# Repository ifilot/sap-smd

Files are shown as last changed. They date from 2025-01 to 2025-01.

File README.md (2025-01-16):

# Modular 8-bit "Simple as Possible" TTL-Logics Computer




This project showcases the design and construction of a modular 8-bit computer
built with TTL logic units. The core principle behind the project is to create a
**"Simple as Possible"** system, focusing on simplicity, modularity, and
compactness.

SAP-SMD demo

## Key Features

- **TTL Logic-Based Design**: The computer is built using traditional TTL
  (Transistor-Transistor Logic) components, adhering to a fundamental, hands-on
  approach to computing.
- **Modular Architecture**: Designed for modularity, each functional unit (ALU,
  registers, memory, control logic, etc.) is implemented as a separate module,
  allowing for easy debugging, customization, and scalability.
- **Compact Form Factor**: By predominantly using **SMD (Surface-Mount Device)**
  components, the overall size of the computer is significantly reduced compared
  to traditional through-hole designs, making it more efficient and portable.
- **Educational Value**: Serves as an excellent learning resource for
  understanding the basic principles of digital logic, computer architecture,
  and how these concepts come together to form a functional computing system.
- **Customization Potential**: The modular approach allows users to experiment
  with different configurations and expand the system to suit specific needs or
  projects.

## Technical specifications

- 8 bit program counter
- 256 bytes of RAM and 256 bytes of program ROM
- 256 configurable programs via a dip switch
- Three general-purpose register: A, B and T
- Simple ALU allowing for addition and subtraction
- EEPROM-configurable instruction decoder
- Custom assembly language including Python-based assembler

## Goals of the Project

The project aims to:
1. **Simplify Complexity**: Break down the workings of a computer into
   comprehensible modules without unnecessary abstraction.
2. **Promote Learning**: Provide an accessible platform for enthusiasts,
   educators, and students to explore computer design.
3. **Encourage Miniaturization**: Demonstrate how SMD components can be used
   effectively in hobbyist and educational projects to save space while
   maintaining functionality.

## Why SMD Components?

SMD components offer several advantages:
- **Space Efficiency**: Significantly smaller than through-hole components,
  enabling more compact designs.
- **Modern Availability**: Easier to source and more reflective of contemporary
  electronics practices.
- **Scalability**: Allows for a more complex system without requiring excessive
  physical space.

## Who Is This For?

This project is ideal for:
- **Hobbyists and Makers** interested in retrocomputing and hardware design.
- **Students and Educators** looking for hands-on experience with digital logic
  and computing fundamentals.
- **Researchers and Enthusiasts** exploring minimalist computing and modular
  design approaches.

## Getting Started

1. **Clone the Repository**: Download the files and schematics from this
   repository.
2. **Review the Documentation**: Detailed explanations and schematics for each
   module are available in the `docs` directory.
3. **Assemble and Test**: Follow the provided instructions to assemble and test
   the modules step-by-step.
4. **Customize**: Modify or expand the design to suit your needs or explore
   specific areas of interest.

## Contributing

Contributions to this project are welcome! If you have ideas for improvements,
additional features, or alternative designs, feel free to fork the repository
and submit a pull request.

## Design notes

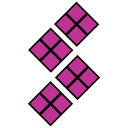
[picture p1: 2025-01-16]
docs/source/_static/img/sap-smd-128px.png

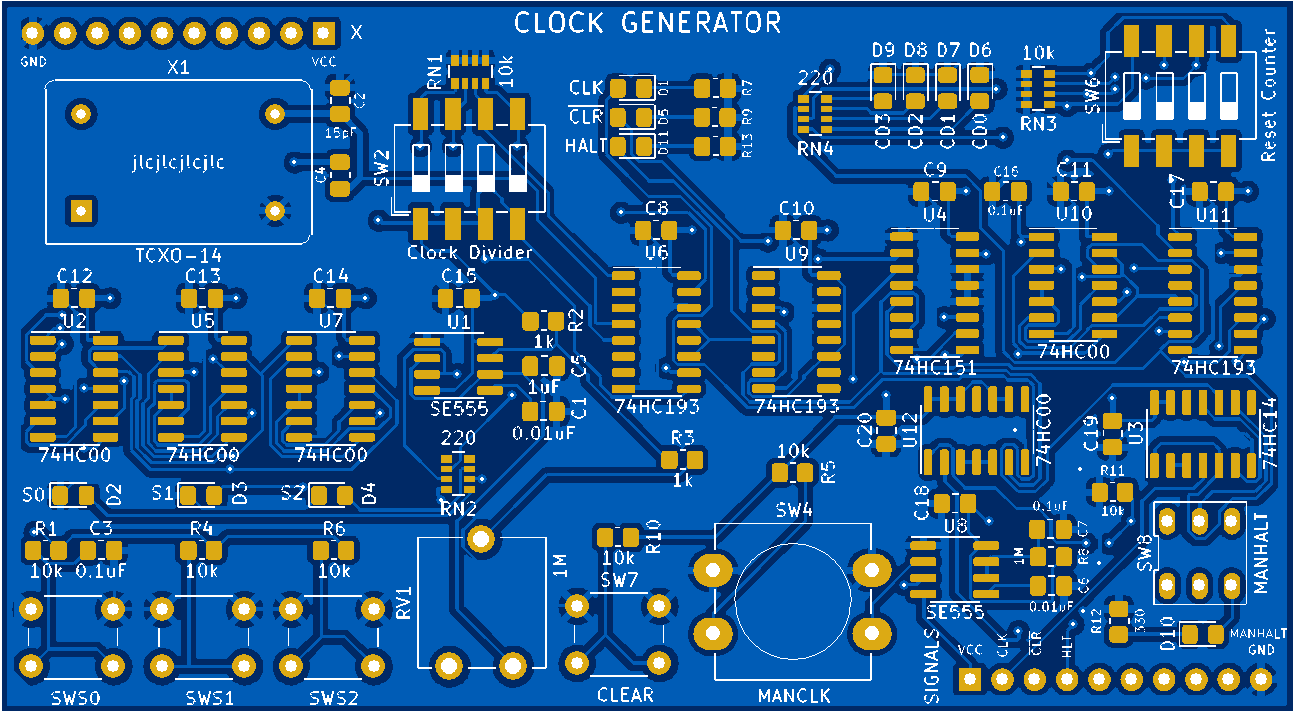
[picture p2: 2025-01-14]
img/clock_generator.png

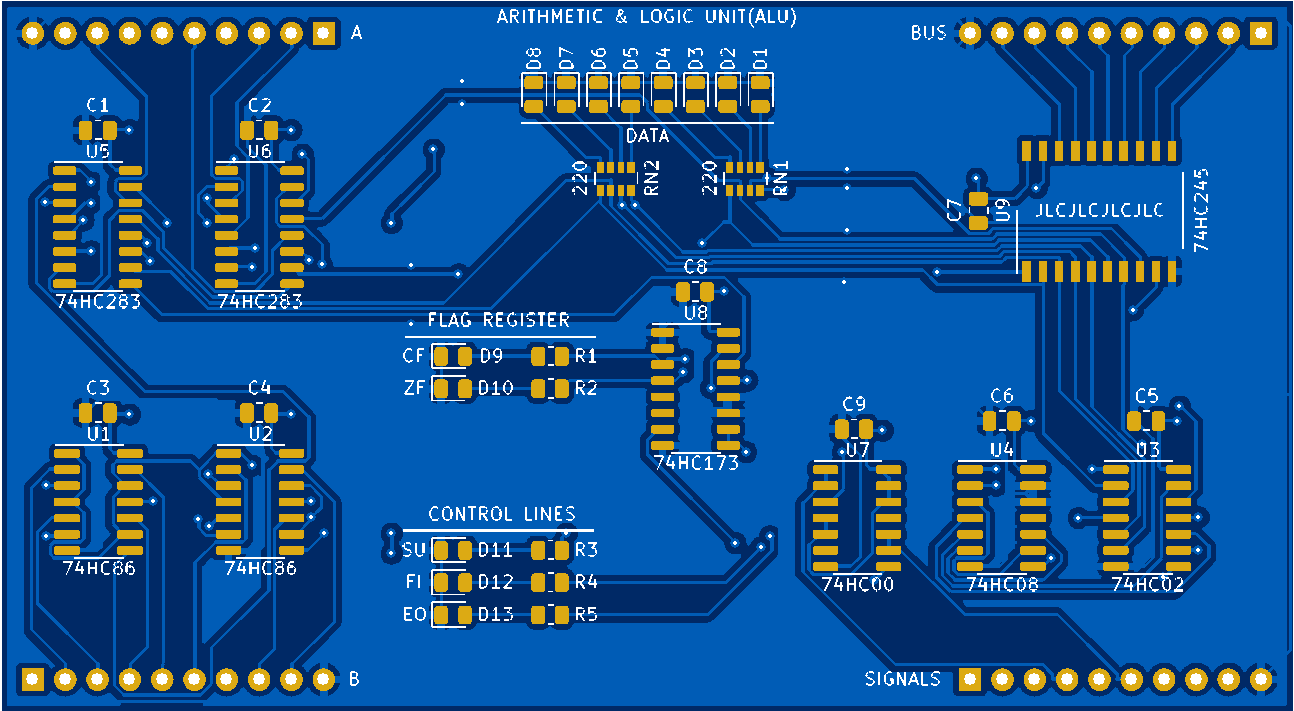
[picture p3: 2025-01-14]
img/arithmetic_and_logic_unit.png

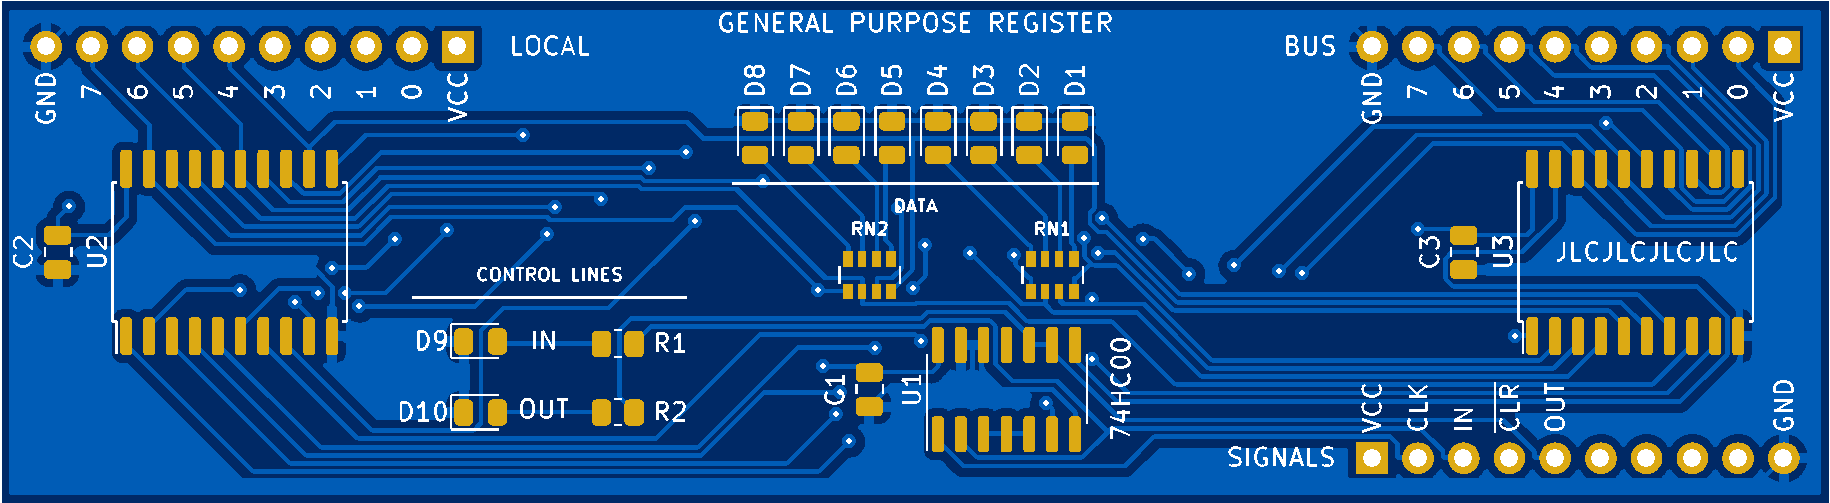
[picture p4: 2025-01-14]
img/general_purpose_register.png

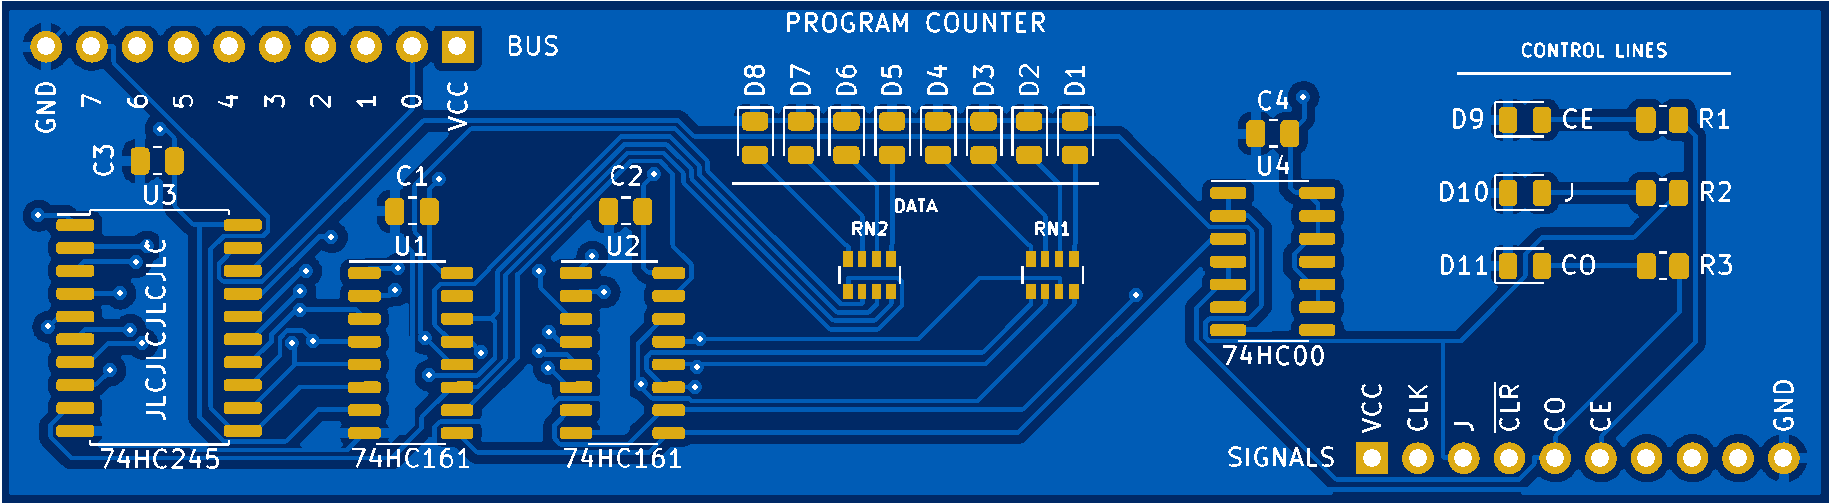
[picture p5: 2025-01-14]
img/program_counter.png

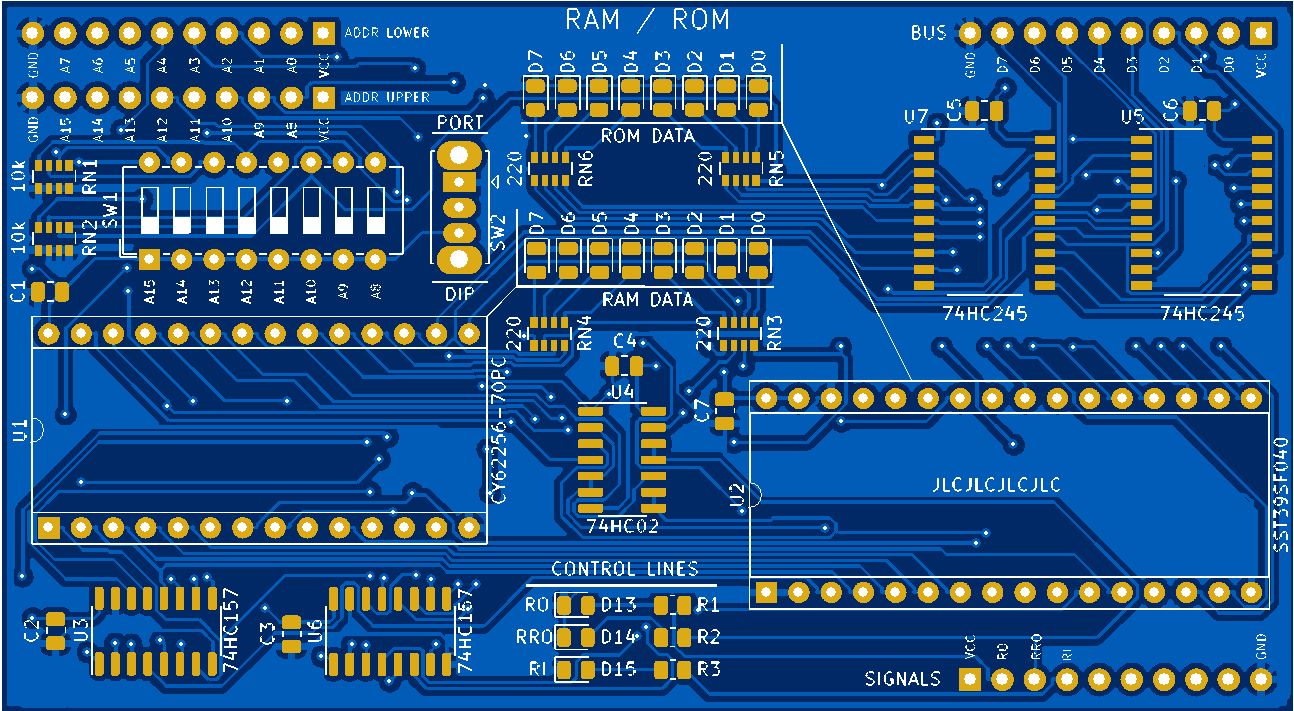
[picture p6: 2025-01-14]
img/ram_rom.png

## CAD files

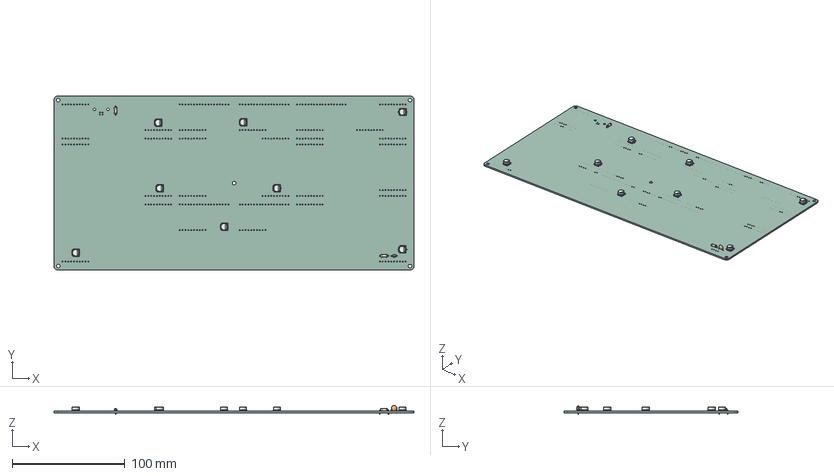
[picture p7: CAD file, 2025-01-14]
pcb/backplates/bp-leanplate/bp-leanplate.step
319.9 x 154.4 x 8.10 mm
CP_Elec_63x39 x 8
R_Axial_DIN0207_L63mm_D25mm_P762mm_Horizontal x 2
C_Disc_D50mm_W25mm_P500mm
bp-leanplate_PCB

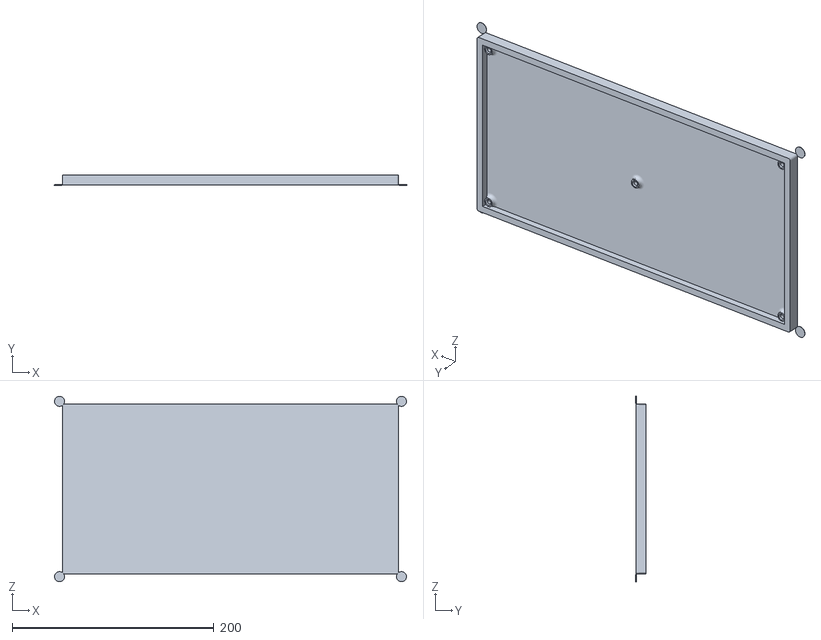
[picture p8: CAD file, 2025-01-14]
pcb/backplates/case/case.stl
349.4 x 10.2 x 184.0

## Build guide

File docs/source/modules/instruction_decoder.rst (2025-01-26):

.. _instruction_decoder:
.. index:: Instruction Decoder

Instruction decoder
===================

The instruction decoder is reponsible for mapping a machine instruction together
with the t-state counter to the control lines, effectively tying a set of
microinstructions to a given machine instruction. The instruction decoder in the
SAM-SMD uses two :code:`SST39SF010` EEPROMS for this mapping. One of the EEPROMS
directs 8 parallel control lines, which are lines that can be pulled high or low
in any particular combination. The second EEPROM is tied to four :code:`74HC238`
which control 2 x 15 orthogonal control lines. Orthogonal control lines are such
that only one of the 15 lines can be activated at one time. This limitation
comes with the benefit that a single chip can control far more control lines,
here 30 instead of 8. Note that the 2 x 15 orthogonal control lines form two
sets, i.e. any control line in one set **can** be activated together with any
other control line in the other set. The only limitation is thus that **within**
a set, no two control lines can be activated simultaneously.

Mapping
-------

.. note::
   In the tables below, we use the following abbreviations:
   * ALU: Arithmetic and Logic Unit
   * IR: Instrucion Register
   * MAR: Memory Address Register
   * PC: Program Counter

.. list-table:: Parallel Control Lines
   :widths: 20, 20, 60
   :header-rows: 1

   * - Control line
     - Micro-instruction
     - Description
   * - :code:`PCL0`
     - :code:`CE`
     - PC count enable
   * - :code:`PCL1`
     - :code:`FI`
     - ALU flag register in
   * - :code:`PCL2`
     - :code:`SU`
     - ALU subtract operation
   * - :code:`PCL3`
     - :code:`X`
     - Unused
   * - :code:`PCL4`
     - :code:`X`
     - Unused
   * - :code:`PCL5`
     - :code:`X`
     - Unused
   * - :code:`PCL6`
     - :code:`HLT`
     - Halts the clock line
   * - :code:`PCL7`
     - :code:`/MR`
     - Used internally to reset T-state counter

.. list-table:: Orthogonal Control Lines A
   :widths: 20, 20, 60
   :header-rows: 1

   * - Control line
     - Micro-instruction
     - Description
   * - :code:`OCA1`
     - :code:`MI`
     - MAR in: Retrieves memory address from data bus
   * - :code:`OCA2`
     - :code:`II`
     - IR in: Retrieves instruction from data bus
   * - :code:`OCA3`
     - :code:`J`
     - PC jump: Retrieves address from data bus
   * - :code:`OCA4`
     - :code:`AI`
     - A-register in: Stores value from data bus
   * - :code:`OCA5`
     - :code:`BI`
     - B-register in: Stores value from data bus
   * - :code:`OCA6`
     - :code:`OI`
     - Output register in: Retrieves value from data bus
   * - :code:`OCA7`
     - :code:`RI`
     - RAM in: Stores value from data bus in memory
   * - :code:`OCA8`
     - :code:`TI`
     - T-register in: Stores value from data bus
   * - :code:`OCA9`
     - :code:`X`
     - Unused
   * - :code:`OCA10`
     - :code:`X`
     - Unused
   * - :code:`OCA11`
     - :code:`X`
     - Unused
   * - :code:`OCA12`
     - :code:`X`
     - Unused
   * - :code:`OCA13`
     - :code:`X`
     - Unused
   * - :code:`OCA14`
     - :code:`X`
     - Unused
   * - :code:`OCA15`
     - :code:`X`
     - Unused

.. list-table:: Orthogonal Control Lines B
   :widths: 20, 20, 60
   :header-rows: 1

   * - Control line
     - Micro-instruction
     - Description
   * - :code:`OCB1`
     - :code:`CO`
     - PC counter out: Asserts current PC value on data bus
   * - :code:`OCB2`
     - :code:`RRO`
     - ROM out: Asserts ROM value onto data bus
   * - :code:`OCB3`
     - :code:`AO`
     - A-register out: Asserts register value onto data bus
   * - :code:`OCB4`
     - :code:`BO`
     - B-register out: Asserts register value onto data bus
   * - :code:`OCB5`
     - :code:`EO`
     - ALU sum out: Asserts result of summation onto data bus
   * - :code:`OCB6`
     - :code:`RO`
     - RAM out: Asserts RAM value onto data bus
   * - :code:`OCB7`
     - :code:`TO`
     - T-register: Asserts register value onto data bus
   * - :code:`OCB8`
     - :code:`X`
     - Unused
   * - :code:`OCB9`
     - :code:`X`
     - Unused
   * - :code:`OCB10`
     - :code:`X`
     - Unused
   * - :code:`OCB11`
     - :code:`X`
     - Unused
   * - :code:`OCB12`
     - :code:`X`
     - Unused
   * - :code:`OCB13`
     - :code:`X`
     - Unused
   * - :code:`OCB14`
     - :code:`X`
     - Unused
   * - :code:`OCB15`
     - :code:`X`
     - Unused

Machine instructions
--------------------

Upon receiving a new machine instruction, a t-state counter is executed that
loops over a number of microinstructions. Below, a table is provided showing
the sequence of microinstructions that are executed per machine instruction
and per t-state. A secondary table provides an explanation what each machine
code instruction (opt code) does.

.. note::
  Despite that the t-state counter allows for up to 20 microinstructions, 
  typically far fewer such microinstructions are needed.

.. list-table:: Microinstructions per t-state and per machine instruction
   :header-rows: 1

   * - Instruction
     - State 0
     - State 1
     - State 2
     - State 3
     - State 4
     - State 5
     - State 6
   * - :code:`NOP`
     - :code:`CO | MI`
     - :code:`RRO | II | CE`
     - :code:`RT`
     - 
     - 
     - 
     - 
   * - :code:`JP`
     - :code:`CO | MI`
     - :code:`RRO | II | CE`
     - :code:`CO | MI`
     - :code:`RRO | J`
     - :code:`RT`
     - 
     - 
   * - :code:`LDA`
     - :code:`CO | MI`
     - :code:`RRO | II | CE`
     - :code:`CO | MI`
     - :code:`RRO | AI | CE`
     - :code:`RT`
     - 
     - 
   * - :code:`LDB`
     - :code:`CO | MI`
     - :code:`RRO | II | CE`
     - :code:`CO | MI`
     - :code:`RRO | BI | CE`
     - :code:`RT`
     - 
     - 
   * - :code:`ADD`
     - :code:`CO | MI`
     - :code:`RRO | II | CE`
     - :code:`0`
     - :code:`EO | TI | FI`
     - :code:`TO | AI`
     - :code:`RT`
     - 
   * - :code:`TAB`
     - :code:`CO | MI`
     - :code:`RRO | II | CE`
     - :code:`AO | BI`
     - :code:`RT`
     - 
     - 
     - 
   * - :code:`TBA`
     - :code:`CO | MI`
     - :code:`RRO | II | CE`
     - :code:`BO | AI`
     - :code:`RT`
     - 
     - 
     - 
   * - :code:`TAO`
     - :code:`CO | MI`
     - :code:`RRO | II | CE`
     - :code:`AO | OI`
     - :code:`RT`
     - 
     - 
     - 
   * - :code:`STA`
     - :code:`CO | MI`
     - :code:`RRO | II | CE`
     - :code:`CO | MI`
     - :code:`RRO | TI`
     - :code:`TO | MI`
     - :code:`RI | AO | CE`
     - :code:`RT`
   * - :code:`LRA`
     - :code:`CO | MI`
     - :code:`RRO | II | CE`
     - :code:`CO | MI`
     - :code:`RRO | TI`
     - :code:`TO | MI`
     - :code:`RO | AI | CE`
     - :code:`RT`
   * - :code:`STB`
     - :code:`CO | MI`
     - :code:`RRO | II | CE`
     - :code:`CO | MI`
     - :code:`RRO | TI`
     - :code:`TO | MI`
     - :code:`RI | BO | CE`
     - :code:`RT`
   * - :code:`LRB`
     - :code:`CO | MI`
     - :code:`RRO | II | CE`
     - :code:`CO | MI`
     - :code:`RRO | TI`
     - :code:`TO | MI`
     - :code:`RO | BI | CE`
     - :code:`RT`

.. list-table:: Explanation of every opt code
   :header-rows: 1

   * - Instruction
     - Bytes
     - Description
   * - :code:`NOP`
     - 1
     - Do nothing
   * - :code:`JP <ADDR>`
     - 2
     - Jump to memory address
   * - :code:`LDA <VAL>`
     - 2
     - Immediate load into register A
   * - :code:`LDB <VAL>`
     - 2
     - Immediate load into register B
   * - :code:`ADD`
     - 1
     - Add A+B and store in A (will overwrite)
   * - :code:`TAB`
     - 1
     - Transfer contents of A to B
   * - :code:`TBA`
     - 1
     - Transfer contents of B to A
   * - :code:`TAO`
     - 1
     - Transfer contents of A to Output
   * - :code:`STA <ADDR>`
     - 2
     - Store A in RAM at address
   * - :code:`LRA <ADDR>`
     - 2
     - Load A from RAM
   * - :code:`STB <ADDR>`
     - 2
     - Store B in RAM at address
   * - :code:`LRB <ADDR>`
     - 2
     - Load B from RAM

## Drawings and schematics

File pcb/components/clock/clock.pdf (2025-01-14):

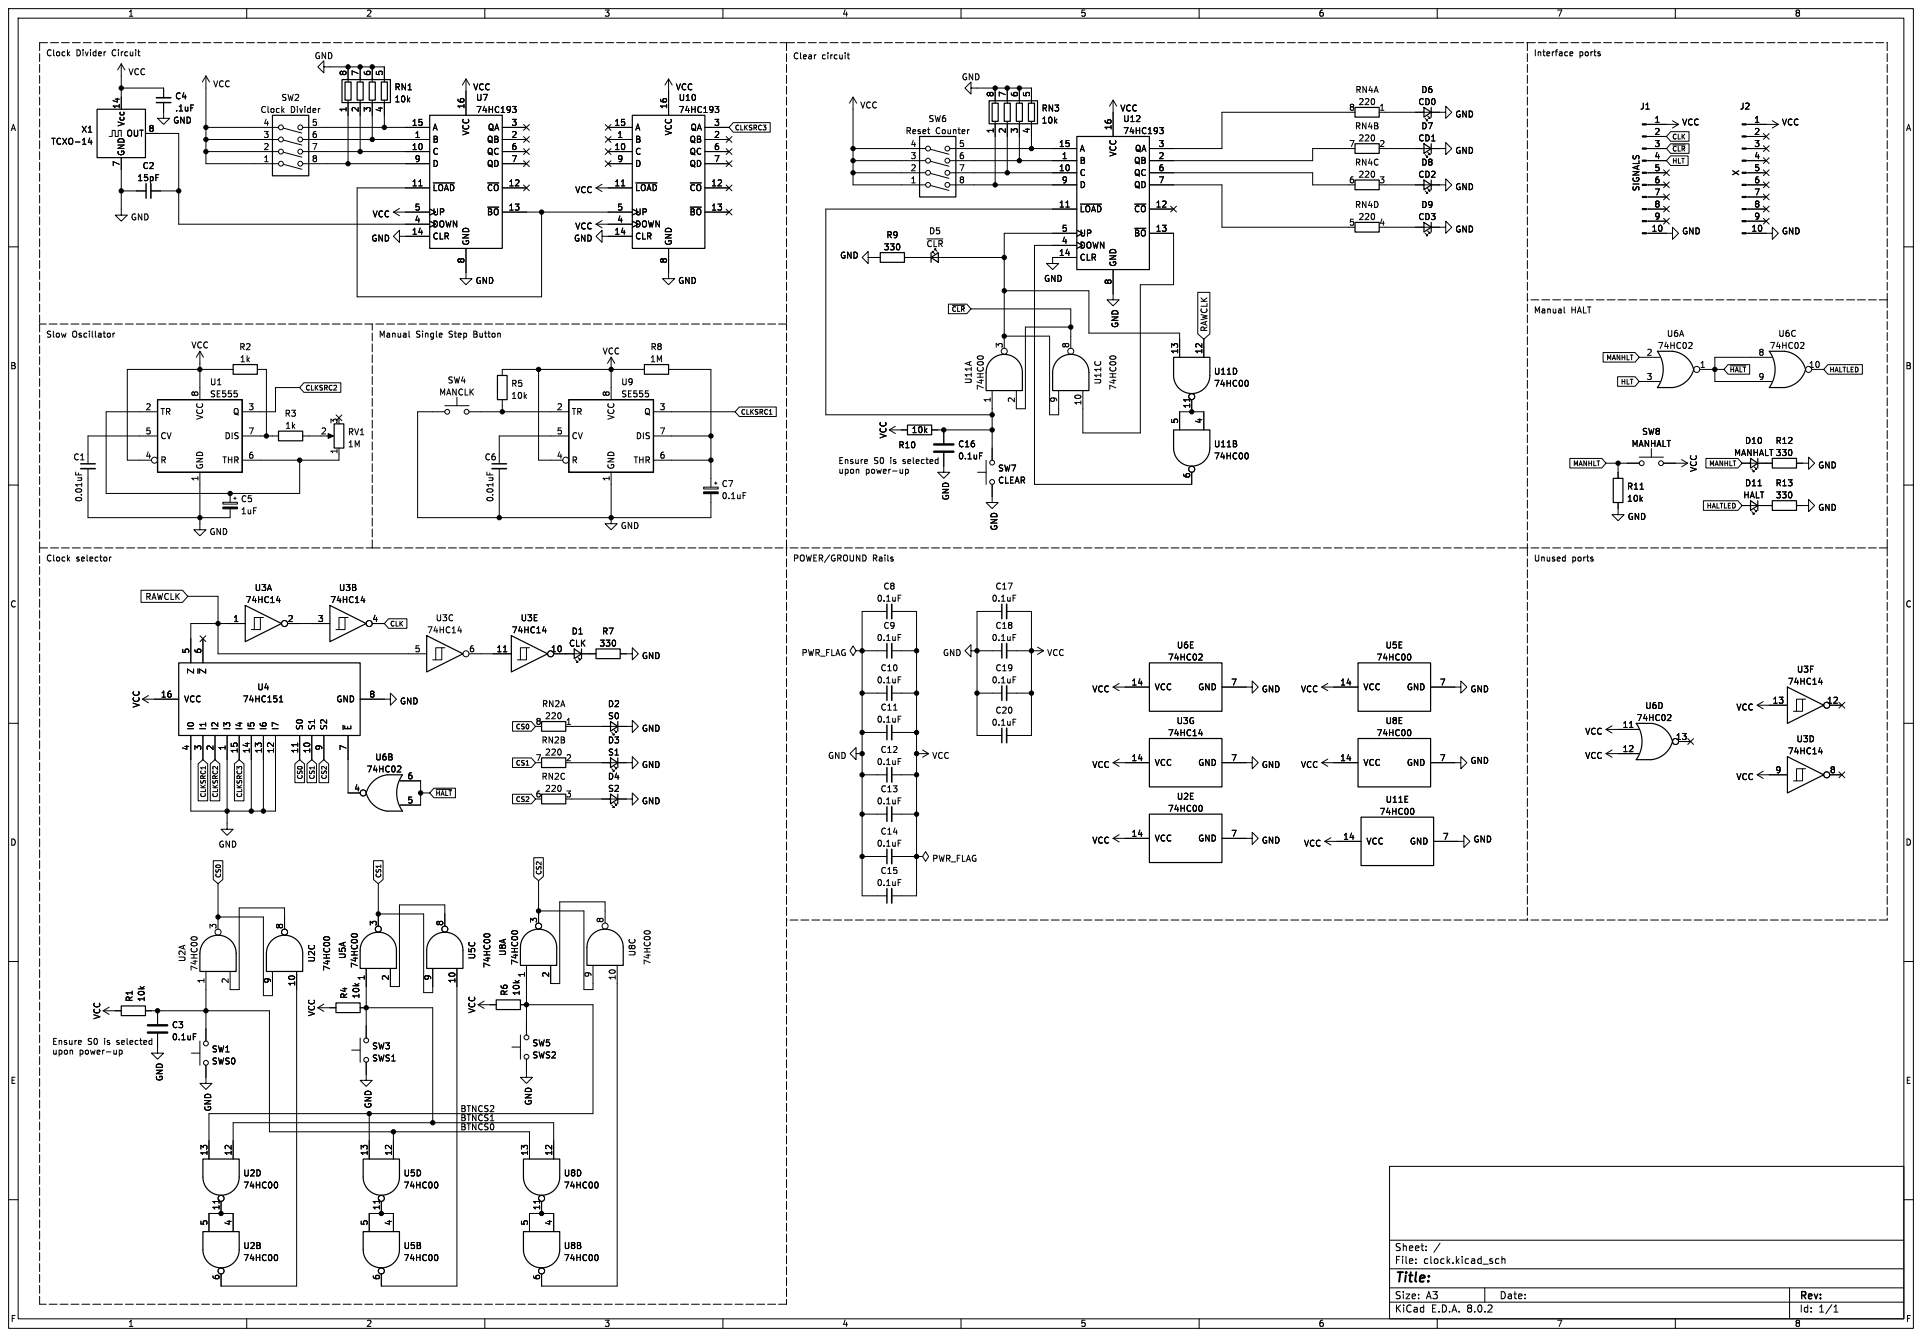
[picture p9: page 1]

6 VCC GND GND GND

Id: 1/1 Title: File: clock.kicad_sch Sheet: /

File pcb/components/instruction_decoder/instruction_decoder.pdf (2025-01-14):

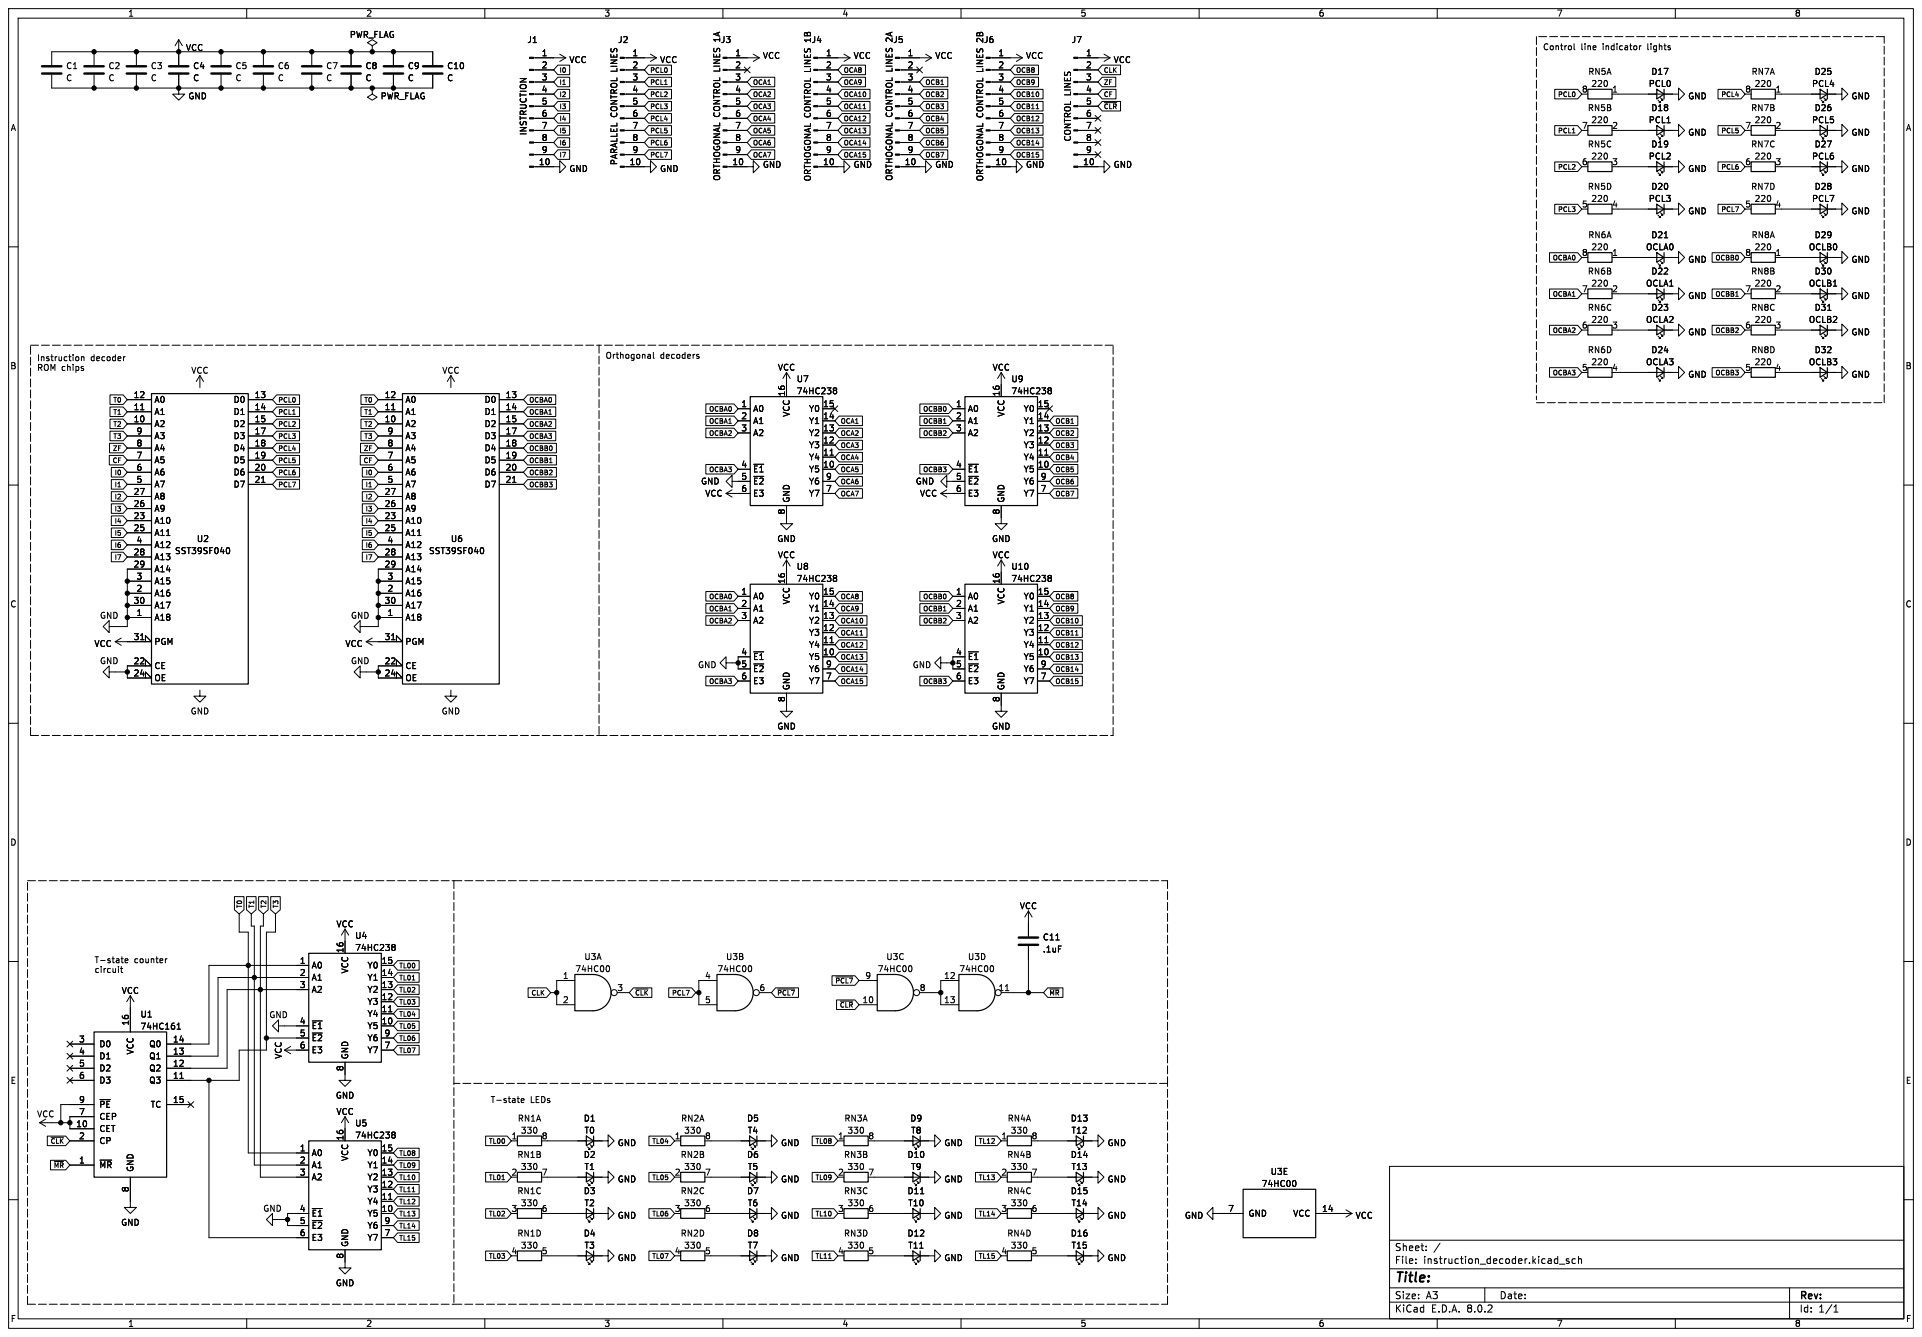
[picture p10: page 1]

8 Y6 9 GND GND GND GND

GND
Id: 1/1 Title: File: instruction_decoder.kicad_sch Sheet: / D7T6

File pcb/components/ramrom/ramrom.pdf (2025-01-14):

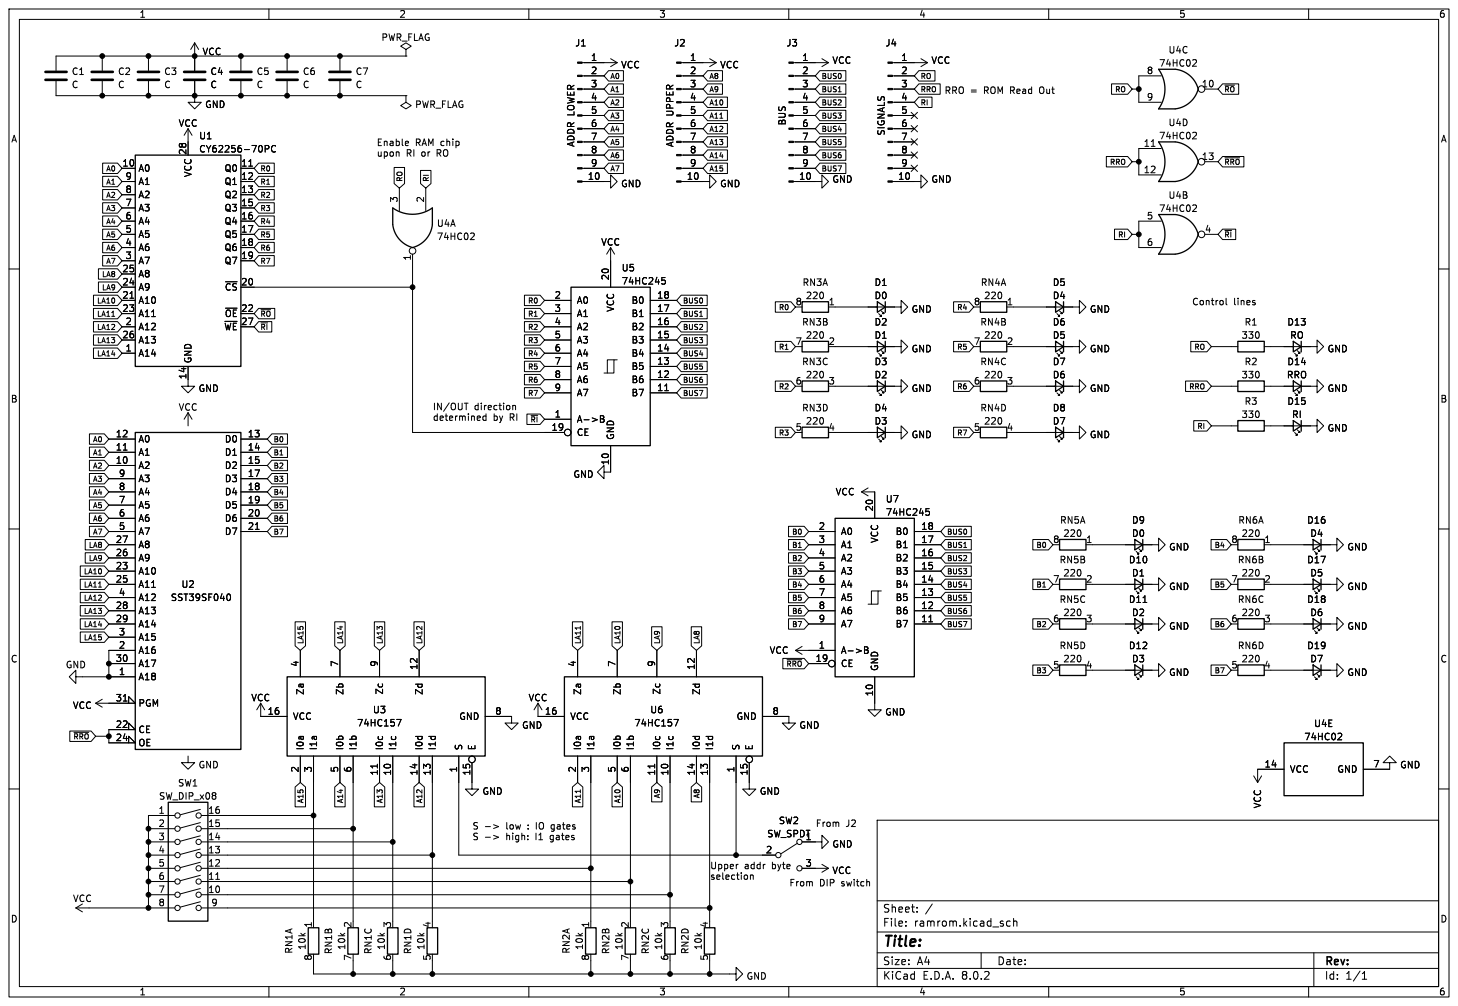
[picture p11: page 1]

4 5 RN1D 10k A3A5 BUS3 BUS1 BUS0 BUS4 BUS7 BUS6 BUS2 BUS5 R7 R6~{RI} R1 R3 R2 R4 R0 ~{RRO} R5 ~{RI} ~{RO} RO

upon RI or RO

7 GND 8 Zc 9 GND GND GND

7 GND 8 Zc 9 VCC GND

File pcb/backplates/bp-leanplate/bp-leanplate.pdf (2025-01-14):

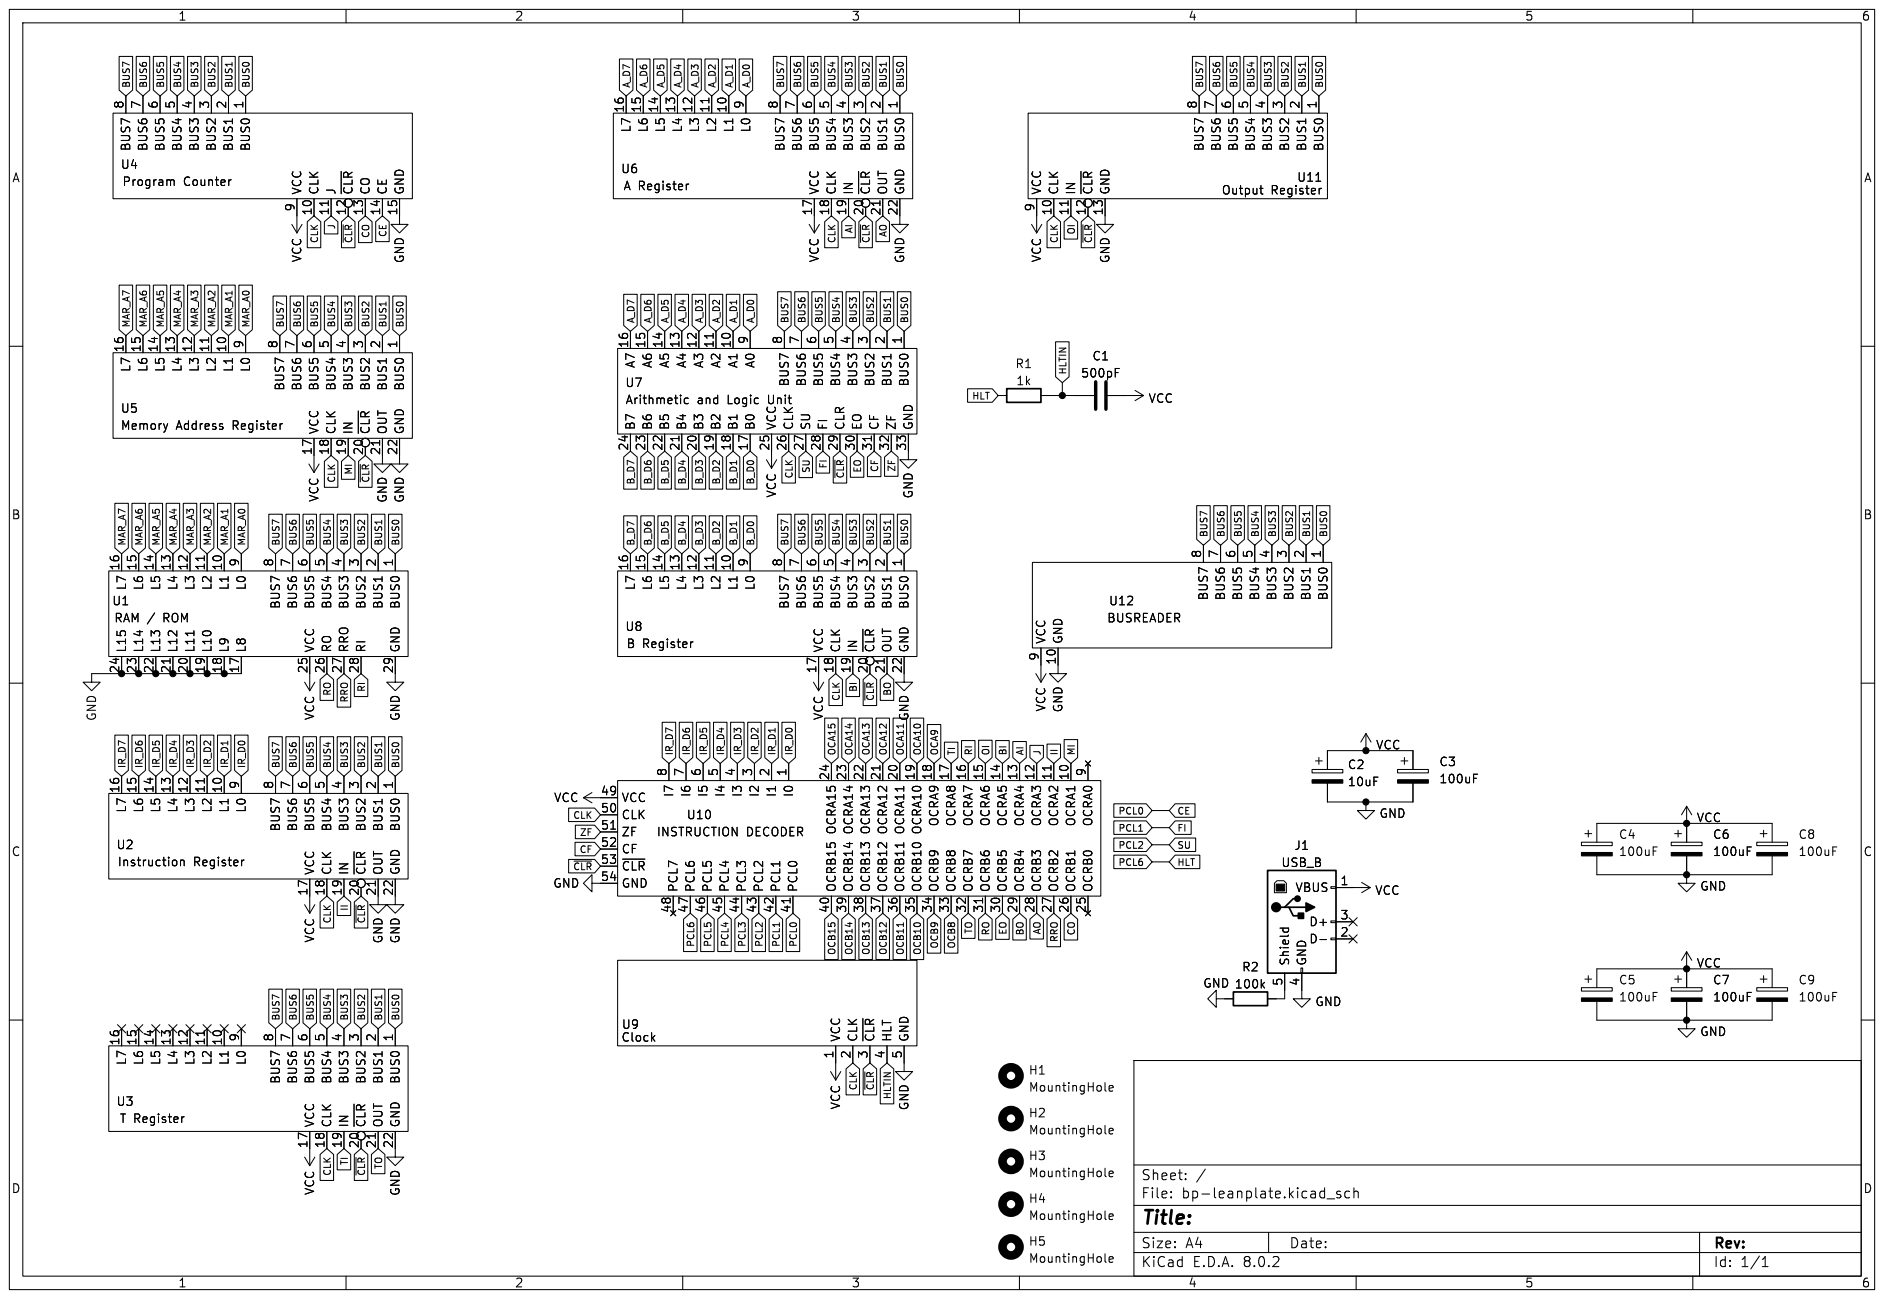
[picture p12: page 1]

Id: 1/1 Title: File: bp-leanplate.kicad_sch Sheet: / GND

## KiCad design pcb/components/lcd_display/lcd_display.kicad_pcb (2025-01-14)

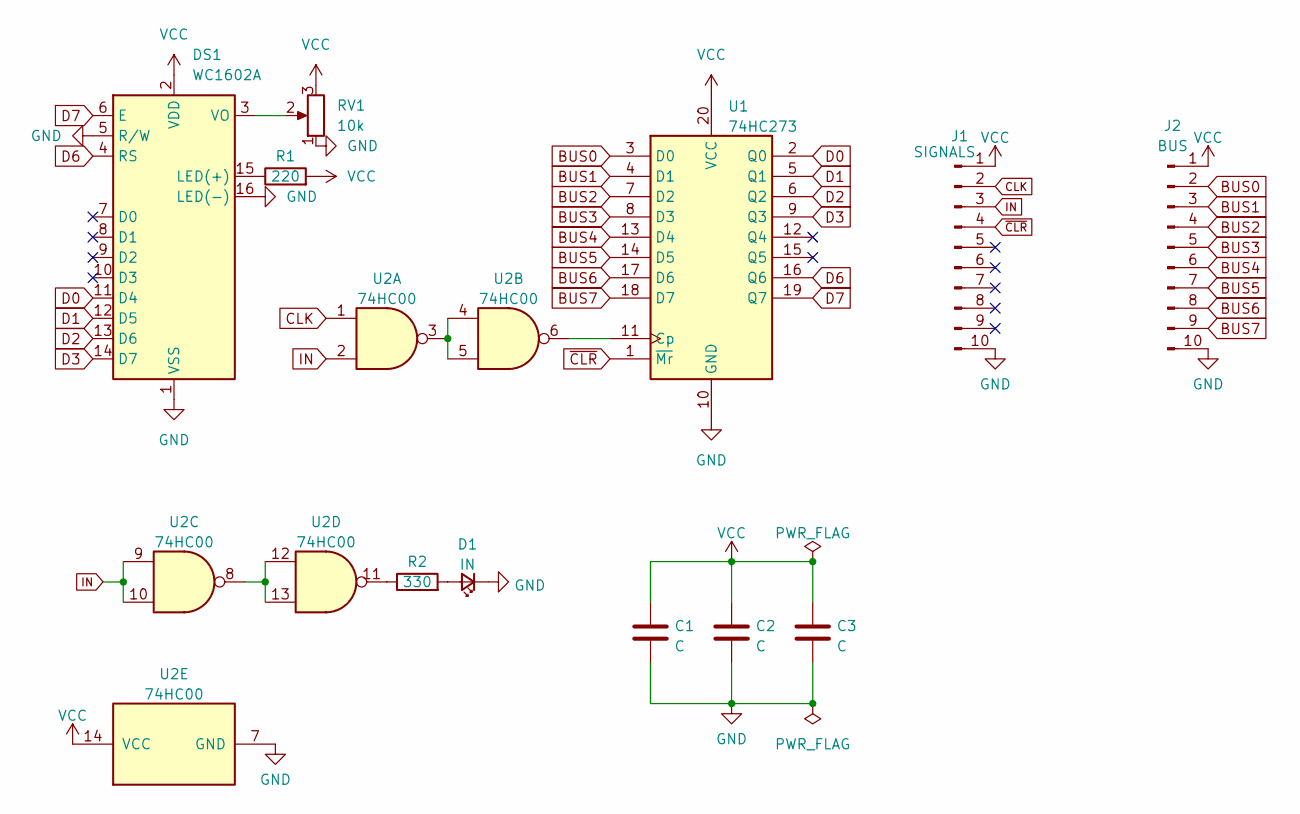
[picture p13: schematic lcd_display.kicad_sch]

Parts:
C1, C2, C3: C; C_0805_2012Metric
D1: IN; LED_0805_2012Metric
DS1: WC1602A
J1: SIGNALS; PinHeader_1x10_P2.54mm_Vertical
J2: BUS; PinHeader_1x10_P2.54mm_Vertical
R1: 220; R_0805_2012Metric
R2: 330; R_0805_2012Metric
RV1: 10k; Potentiometer_Bourns_3296W_Vertical
U1: 74HC273; SOIC-20W_7.5x12.8mm_P1.27mm
U2: 74HC00; SO-14_3.9x8.65mm_P1.27mm

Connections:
BUS0: J2.2, U1.3 (D0)
BUS1: J2.3, U1.4 (D1)
BUS2: J2.4, U1.7 (D2)
BUS3: J2.5, U1.8 (D3)
BUS4: J2.6, U1.13 (D4)
BUS5: J2.7, U1.14 (D5)
BUS6: J2.8, U1.17 (D6)
BUS7: J2.9, U1.18 (D7)
CLK: J1.2, U2.1
D0: DS1.11 (D4), U1.2 (Q0)
D1: DS1.12 (D5), U1.5 (Q1)
D2: DS1.13 (D6), U1.6 (Q2)
D3: DS1.14 (D7), U1.9 (Q3)
D6: DS1.4 (RS), U1.16 (Q6)
D7: DS1.6 (E), U1.19 (Q7)
GND: C1.2, C2.2, C3.2, D1.1 (K), DS1.1 (VSS), DS1.5 (R/W), DS1.16 (LED(-)), J1.10, J2.10, RV1.1, U1.10 (GND), U2.7 (GND)
IN: J1.3, U2.2, U2.9, U2.10
unnamed: D1.2 (A), R2.2
unnamed: DS1.15 (LED(+)), R1.1
unnamed: DS1.3 (VO), RV1.2
unnamed: R2.1, U2.11
unnamed: U1.11 (Cp), U2.6
unnamed: U2.3, U2.4, U2.5
unnamed: U2.8, U2.12, U2.13
VCC: C1.1, C2.1, C3.1, DS1.2 (VDD), J1.1, J2.1, R1.2, RV1.3, U1.20 (VCC), U2.14 (VCC)
~CLR: J1.4, U1.1 (~Mr)

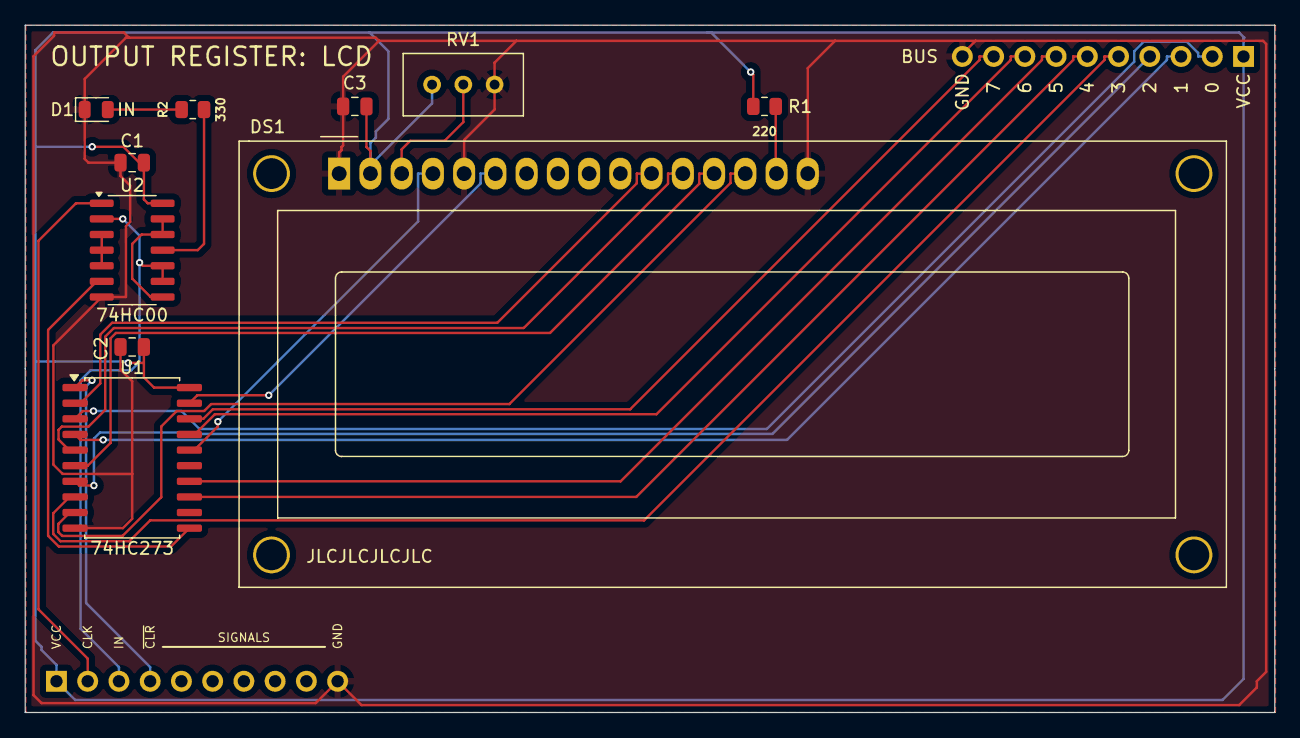
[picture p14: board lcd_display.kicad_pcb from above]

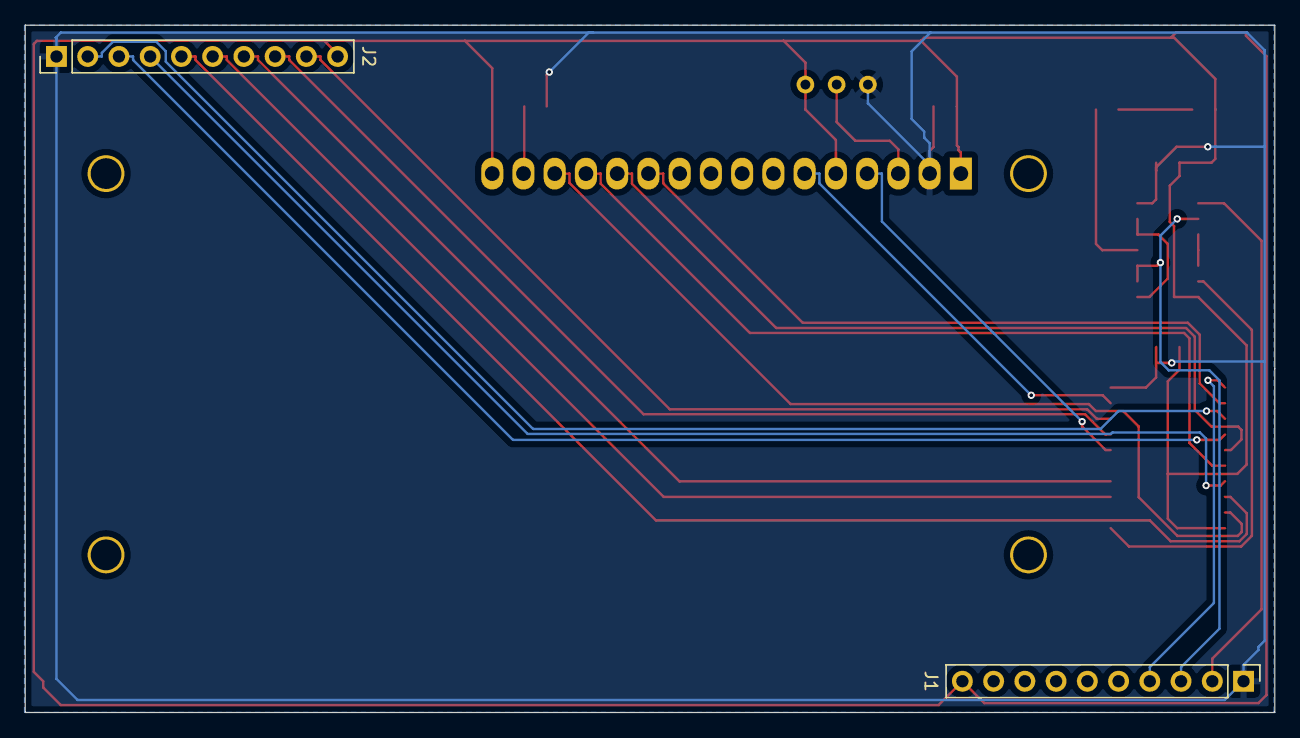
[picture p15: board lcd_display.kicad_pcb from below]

Board: 2 copper layers, 101.6 x 55.9 mm, 12 parts (2 on the bottom side), 26 nets.

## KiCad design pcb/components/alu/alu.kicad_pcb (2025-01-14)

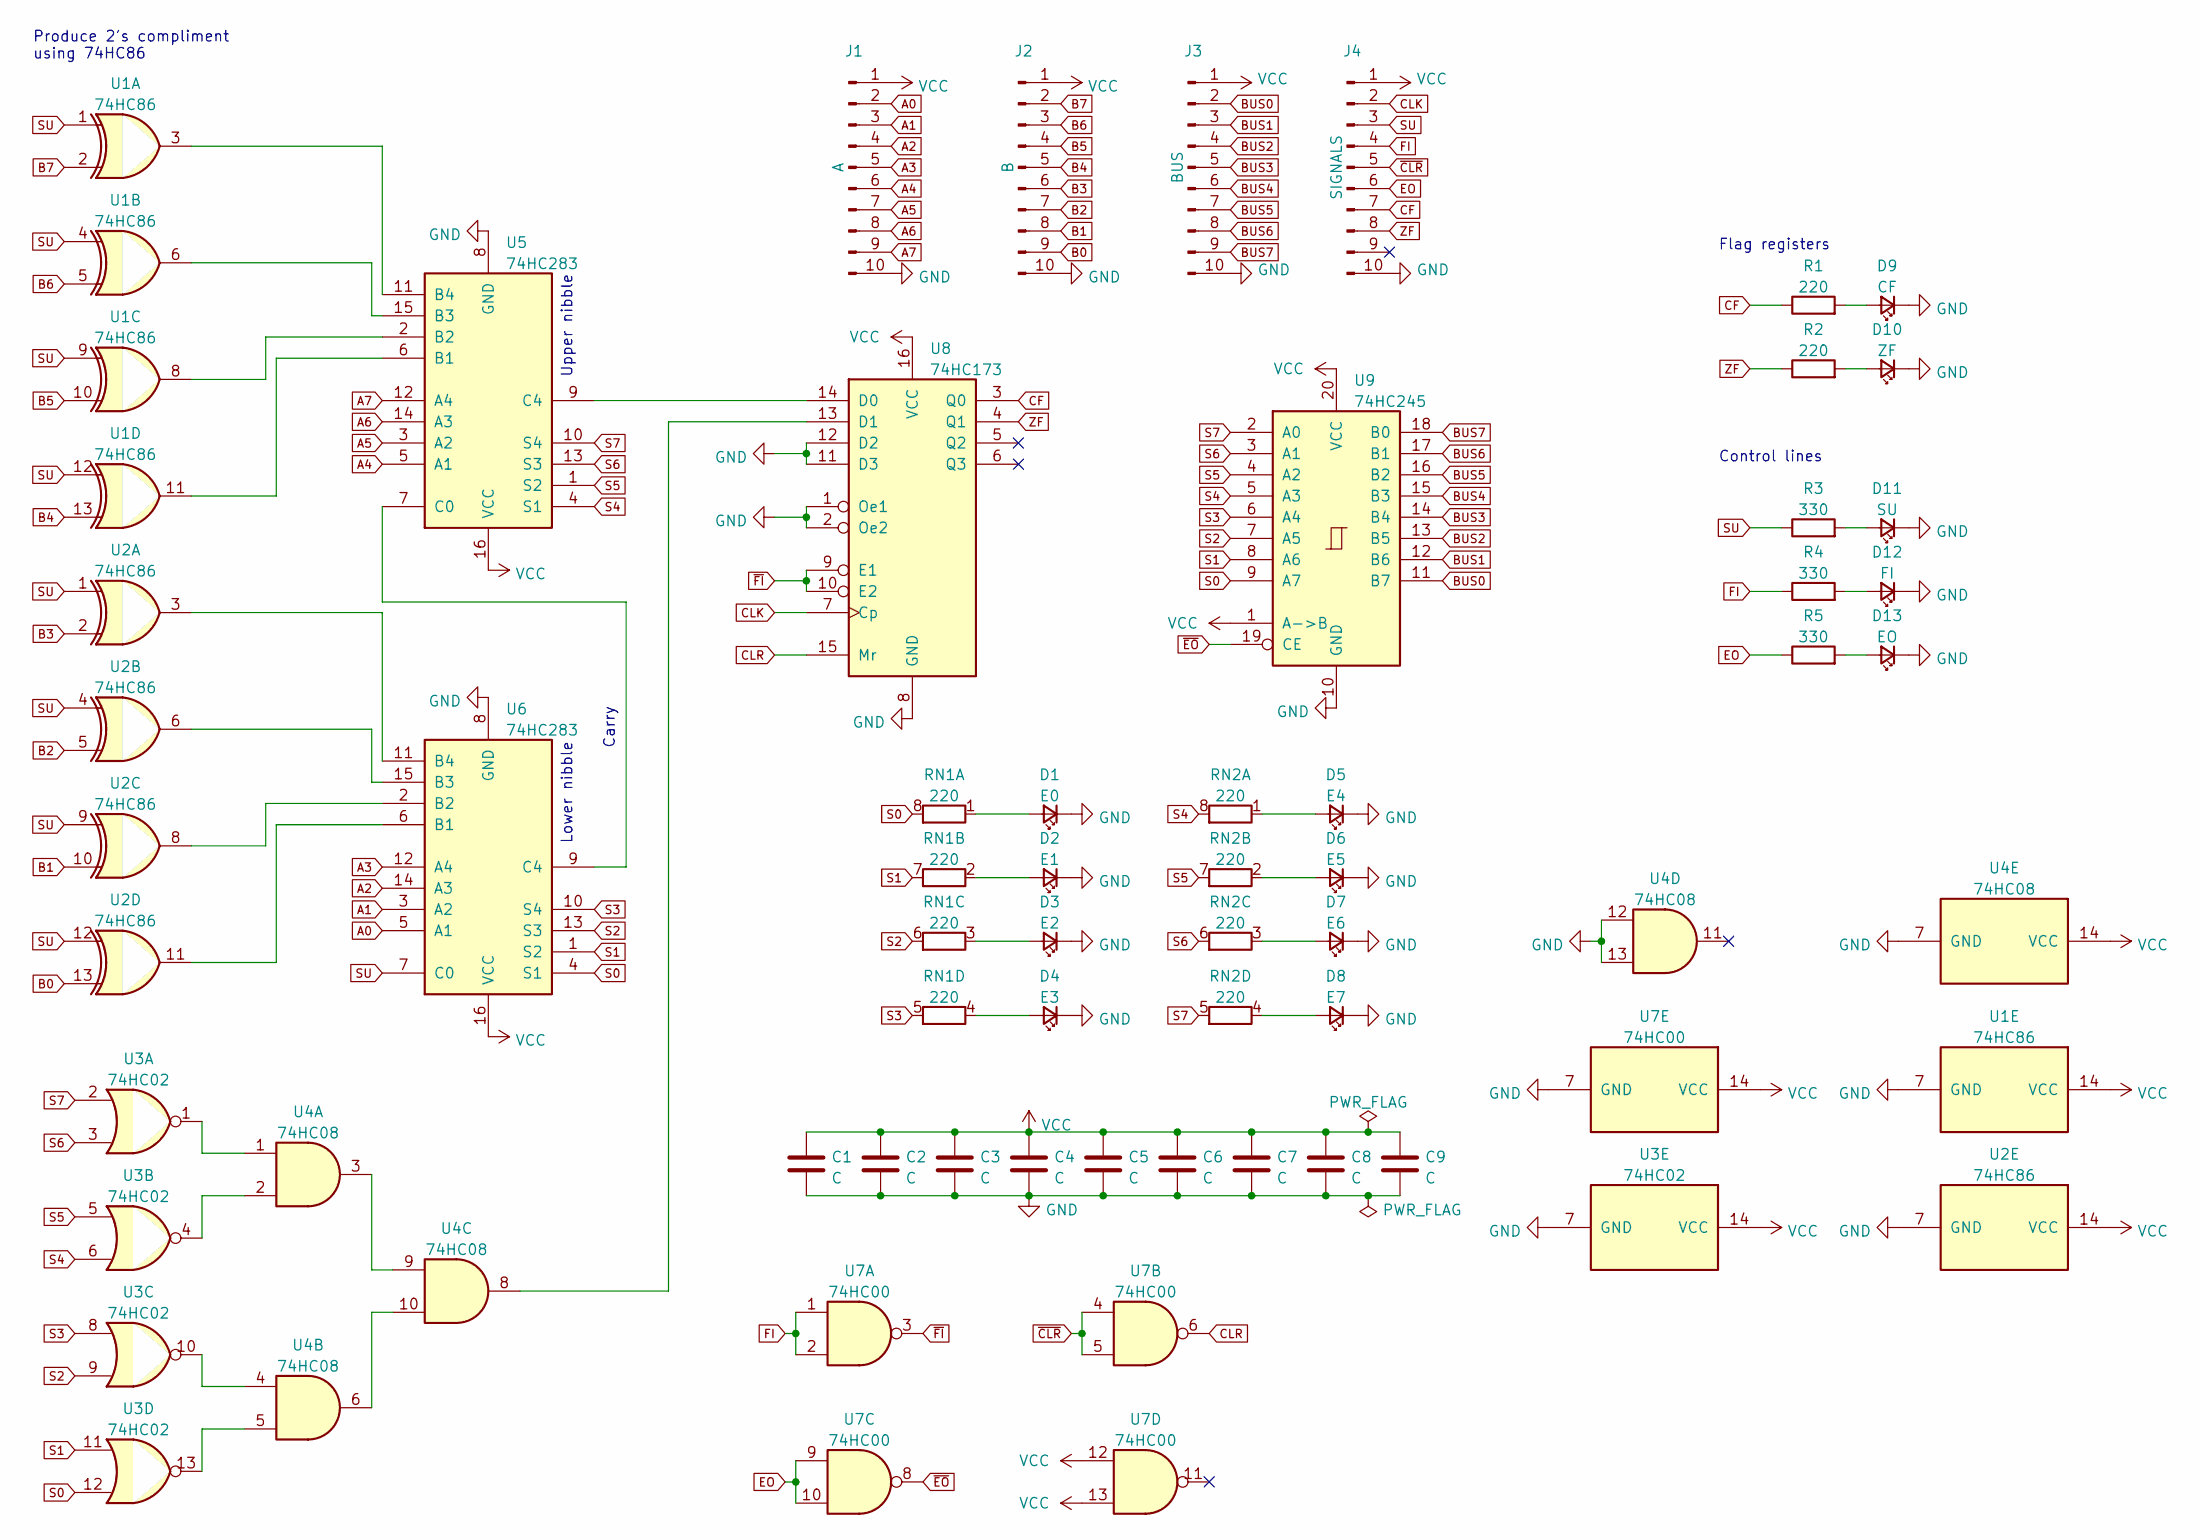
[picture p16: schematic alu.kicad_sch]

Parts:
C1, C2, C3, C4, C5, C6, C7, C8, C9: C; C_0805_2012Metric
D1: E0; LED_0805_2012Metric
D2: E1; LED_0805_2012Metric
D3: E2; LED_0805_2012Metric
D4: E3; LED_0805_2012Metric
D5: E4; LED_0805_2012Metric
D6: E5; LED_0805_2012Metric
D7: E6; LED_0805_2012Metric
D8: E7; LED_0805_2012Metric
D9: CF; LED_0805_2012Metric
D10: ZF; LED_0805_2012Metric
D11: SU; LED_0805_2012Metric
D12: FI; LED_0805_2012Metric
D13: EO; LED_0805_2012Metric
J1: A; PinHeader_1x10_P2.54mm_Vertical
J2: B; PinHeader_1x10_P2.54mm_Vertical
J3: BUS; PinHeader_1x10_P2.54mm_Vertical
J4: SIGNALS; PinHeader_1x10_P2.54mm_Vertical
R1, R2: 220; R_0805_2012Metric
R3, R4, R5: 330; R_0805_2012Metric
RN1, RN2: 220; R_Array_Convex_4x0603
U1, U2: 74HC86; SO-14_3.9x8.65mm_P1.27mm
U3: 74HC02; SO-14_3.9x8.65mm_P1.27mm
U4: 74HC08; SO-14_3.9x8.65mm_P1.27mm
U5, U6: 74HC283; SO-16_3.9x9.9mm_P1.27mm
U7: 74HC00; SO-14_3.9x8.65mm_P1.27mm
U8: 74HC173; SO-16_3.9x9.9mm_P1.27mm
U9: 74HC245; SO-20_12.8x7.5mm_P1.27mm

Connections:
A0: J1.2, U6.5 (A1)
A1: J1.3, U6.3 (A2)
A2: J1.4, U6.14 (A3)
A3: J1.5, U6.12 (A4)
A4: J1.6, U5.5 (A1)
A5: J1.7, U5.3 (A2)
A6: J1.8, U5.14 (A3)
A7: J1.9, U5.12 (A4)
B0: J2.9, U2.13
B1: J2.8, U2.10
B2: J2.7, U2.5
B3: J2.6, U2.2
B4: J2.5, U1.13
B5: J2.4, U1.10
B6: J2.3, U1.5
B7: J2.2, U1.2
BUS0: J3.2, U9.11 (B7)
BUS1: J3.3, U9.12 (B6)
BUS2: J3.4, U9.13 (B5)
BUS3: J3.5, U9.14 (B4)
BUS4: J3.6, U9.15 (B3)
BUS5: J3.7, U9.16 (B2)
BUS6: J3.8, U9.17 (B1)
BUS7: J3.9, U9.18 (B0)
CF: J4.7, R1.1, U8.3 (Q0)
CLK: J4.2, U8.7 (Cp)
CLR: U7.6, U8.15 (Mr)
EO: J4.6, R5.1, U7.9, U7.10
FI: J4.4, R4.1, U7.1, U7.2
GND: C1.2, C2.2, C3.2, C4.2, C5.2, C6.2, C7.2, C8.2, C9.2, D1.1 (K), D2.1 (K), D3.1 (K), D4.1 (K), D5.1 (K), D6.1 (K), D7.1 (K), D8.1 (K), D9.1 (K), D10.1 (K), D11.1 (K), D12.1 (K), D13.1 (K), J1.10, J2.10, J3.10, J4.10, U1.7 (GND), U2.7 (GND), U3.7 (GND), U4.7 (GND), U4.12, U4.13, U5.8 (GND), U6.8 (GND), U7.7 (GND), U8.1 (Oe1), U8.2 (Oe2), U8.8 (GND), U8.11 (D3), U8.12 (D2), U9.10 (GND)
unnamed: D1.2 (A), RN1.1 (R1.1)
unnamed: D2.2 (A), RN1.2 (R2.1)
unnamed: D3.2 (A), RN1.3 (R3.1)
unnamed: D4.2 (A), RN1.4 (R4.1)
unnamed: D5.2 (A), RN2.1 (R1.1)
unnamed: D6.2 (A), RN2.2 (R2.1)
unnamed: D7.2 (A), RN2.3 (R3.1)
unnamed: D8.2 (A), RN2.4 (R4.1)
unnamed: D9.2 (A), R1.2
unnamed: D10.2 (A), R2.2
unnamed: D11.2 (A), R3.2
unnamed: D12.2 (A), R4.2
unnamed: D13.2 (A), R5.2
unnamed: U1.3, U5.11 (B4)
unnamed: U1.6, U5.15 (B3)
unnamed: U1.8, U5.2 (B2)
unnamed: U1.11, U5.6 (B1)
unnamed: U2.3, U6.11 (B4)
unnamed: U2.6, U6.15 (B3)
unnamed: U2.8, U6.2 (B2)
unnamed: U2.11, U6.6 (B1)
unnamed: U3.1, U4.1
unnamed: U3.4, U4.2
unnamed: U3.10, U4.4
unnamed: U3.13, U4.5
unnamed: U4.3, U4.9
unnamed: U4.8, U8.13 (D1)
unnamed: U4.6, U4.10
unnamed: U5.7 (C0), U6.9 (C4)
unnamed: U5.9 (C4), U8.14 (D0)
S0: RN1.8 (R1.2), U3.12, U6.4 (S1), U9.9 (A7)
S1: RN1.7 (R2.2), U3.11, U6.1 (S2), U9.8 (A6)
S2: RN1.6 (R3.2), U3.9, U6.13 (S3), U9.7 (A5)
S3: RN1.5 (R4.2), U3.8, U6.10 (S4), U9.6 (A4)
S4: RN2.8 (R1.2), U3.6, U5.4 (S1), U9.5 (A3)
S5: RN2.7 (R2.2), U3.5, U5.1 (S2), U9.4 (A2)
S6: RN2.6 (R3.2), U3.3, U5.13 (S3), U9.3 (A1)
S7: RN2.5 (R4.2), U3.2, U5.10 (S4), U9.2 (A0)
SU: J4.3, R3.1, U1.1, U1.4, U1.9, U1.12, U2.1, U2.4, U2.9, U2.12, U6.7 (C0)
VCC: C1.1, C2.1, C3.1, C4.1, C5.1, C6.1, C7.1, C8.1, C9.1, J1.1, J2.1, J3.1, J4.1, U1.14 (VCC), U2.14 (VCC), U3.14 (VCC), U4.14 (VCC), U5.16 (VCC), U6.16 (VCC), U7.12, U7.13, U7.14 (VCC), U8.16 (VCC), U9.1 (A->B), U9.20 (VCC)
ZF: J4.8, R2.1, U8.4 (Q1)
~CLR: J4.5, U7.4, U7.5
~EO: U7.8, U9.19 (CE)
~FI: U7.3, U8.9 (E1), U8.10 (E2)

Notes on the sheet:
Produce 2's compliment using 74HC86
Control lines
Flag registers
Upper nibble
Carry
Lower nibble

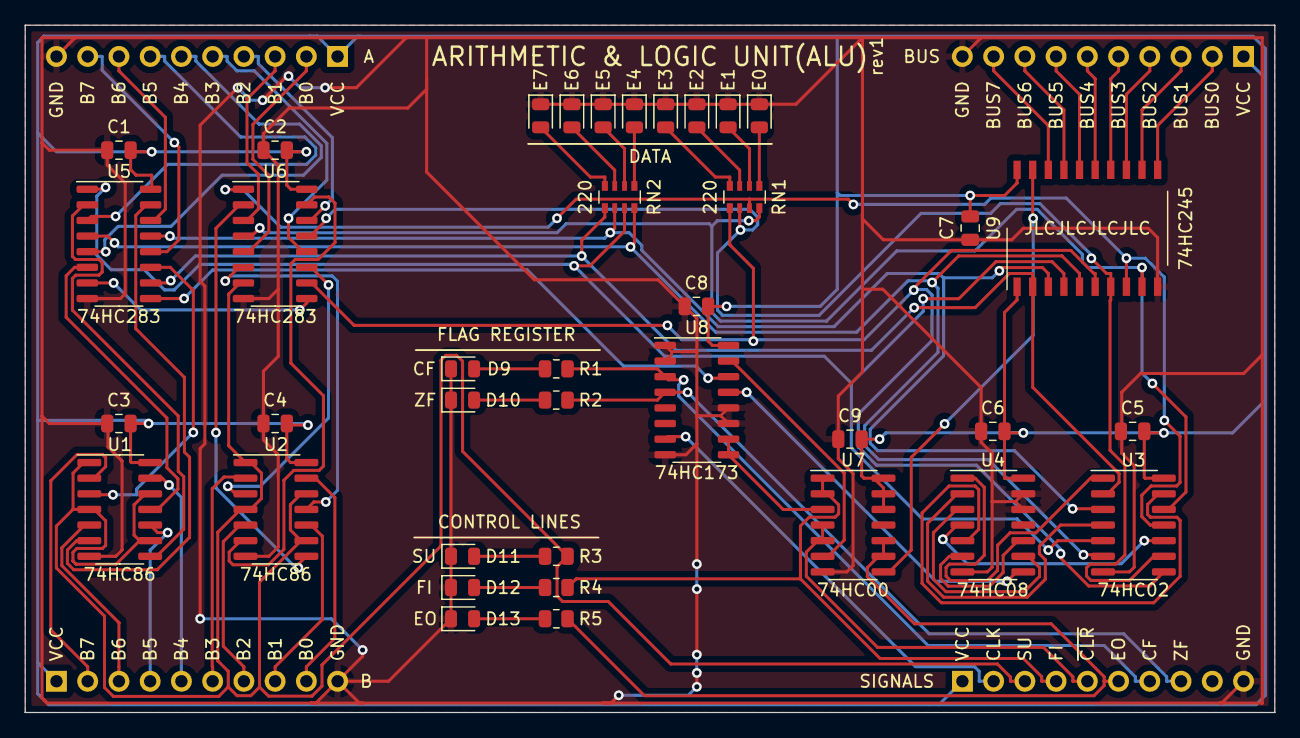
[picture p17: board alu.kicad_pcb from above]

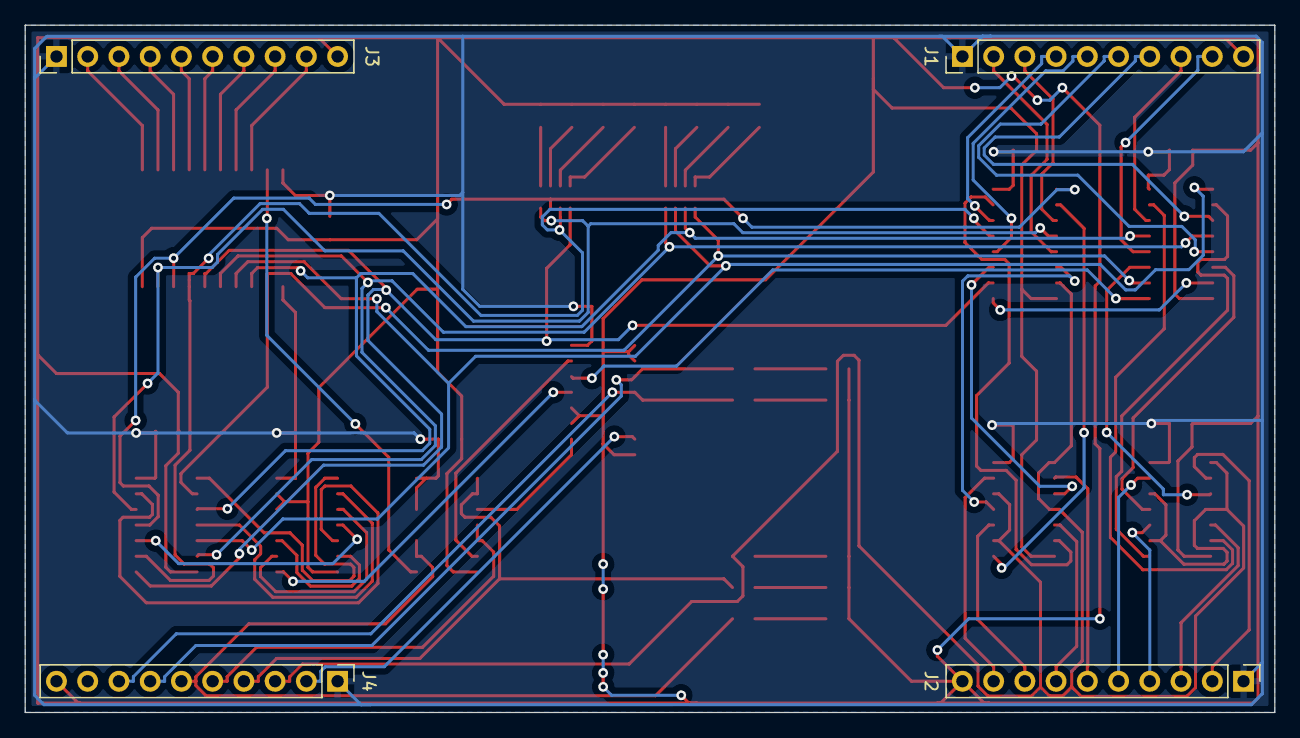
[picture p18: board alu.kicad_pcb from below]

Board: 2 copper layers, 101.6 x 55.9 mm, 42 parts (4 on the bottom side), 74 nets.

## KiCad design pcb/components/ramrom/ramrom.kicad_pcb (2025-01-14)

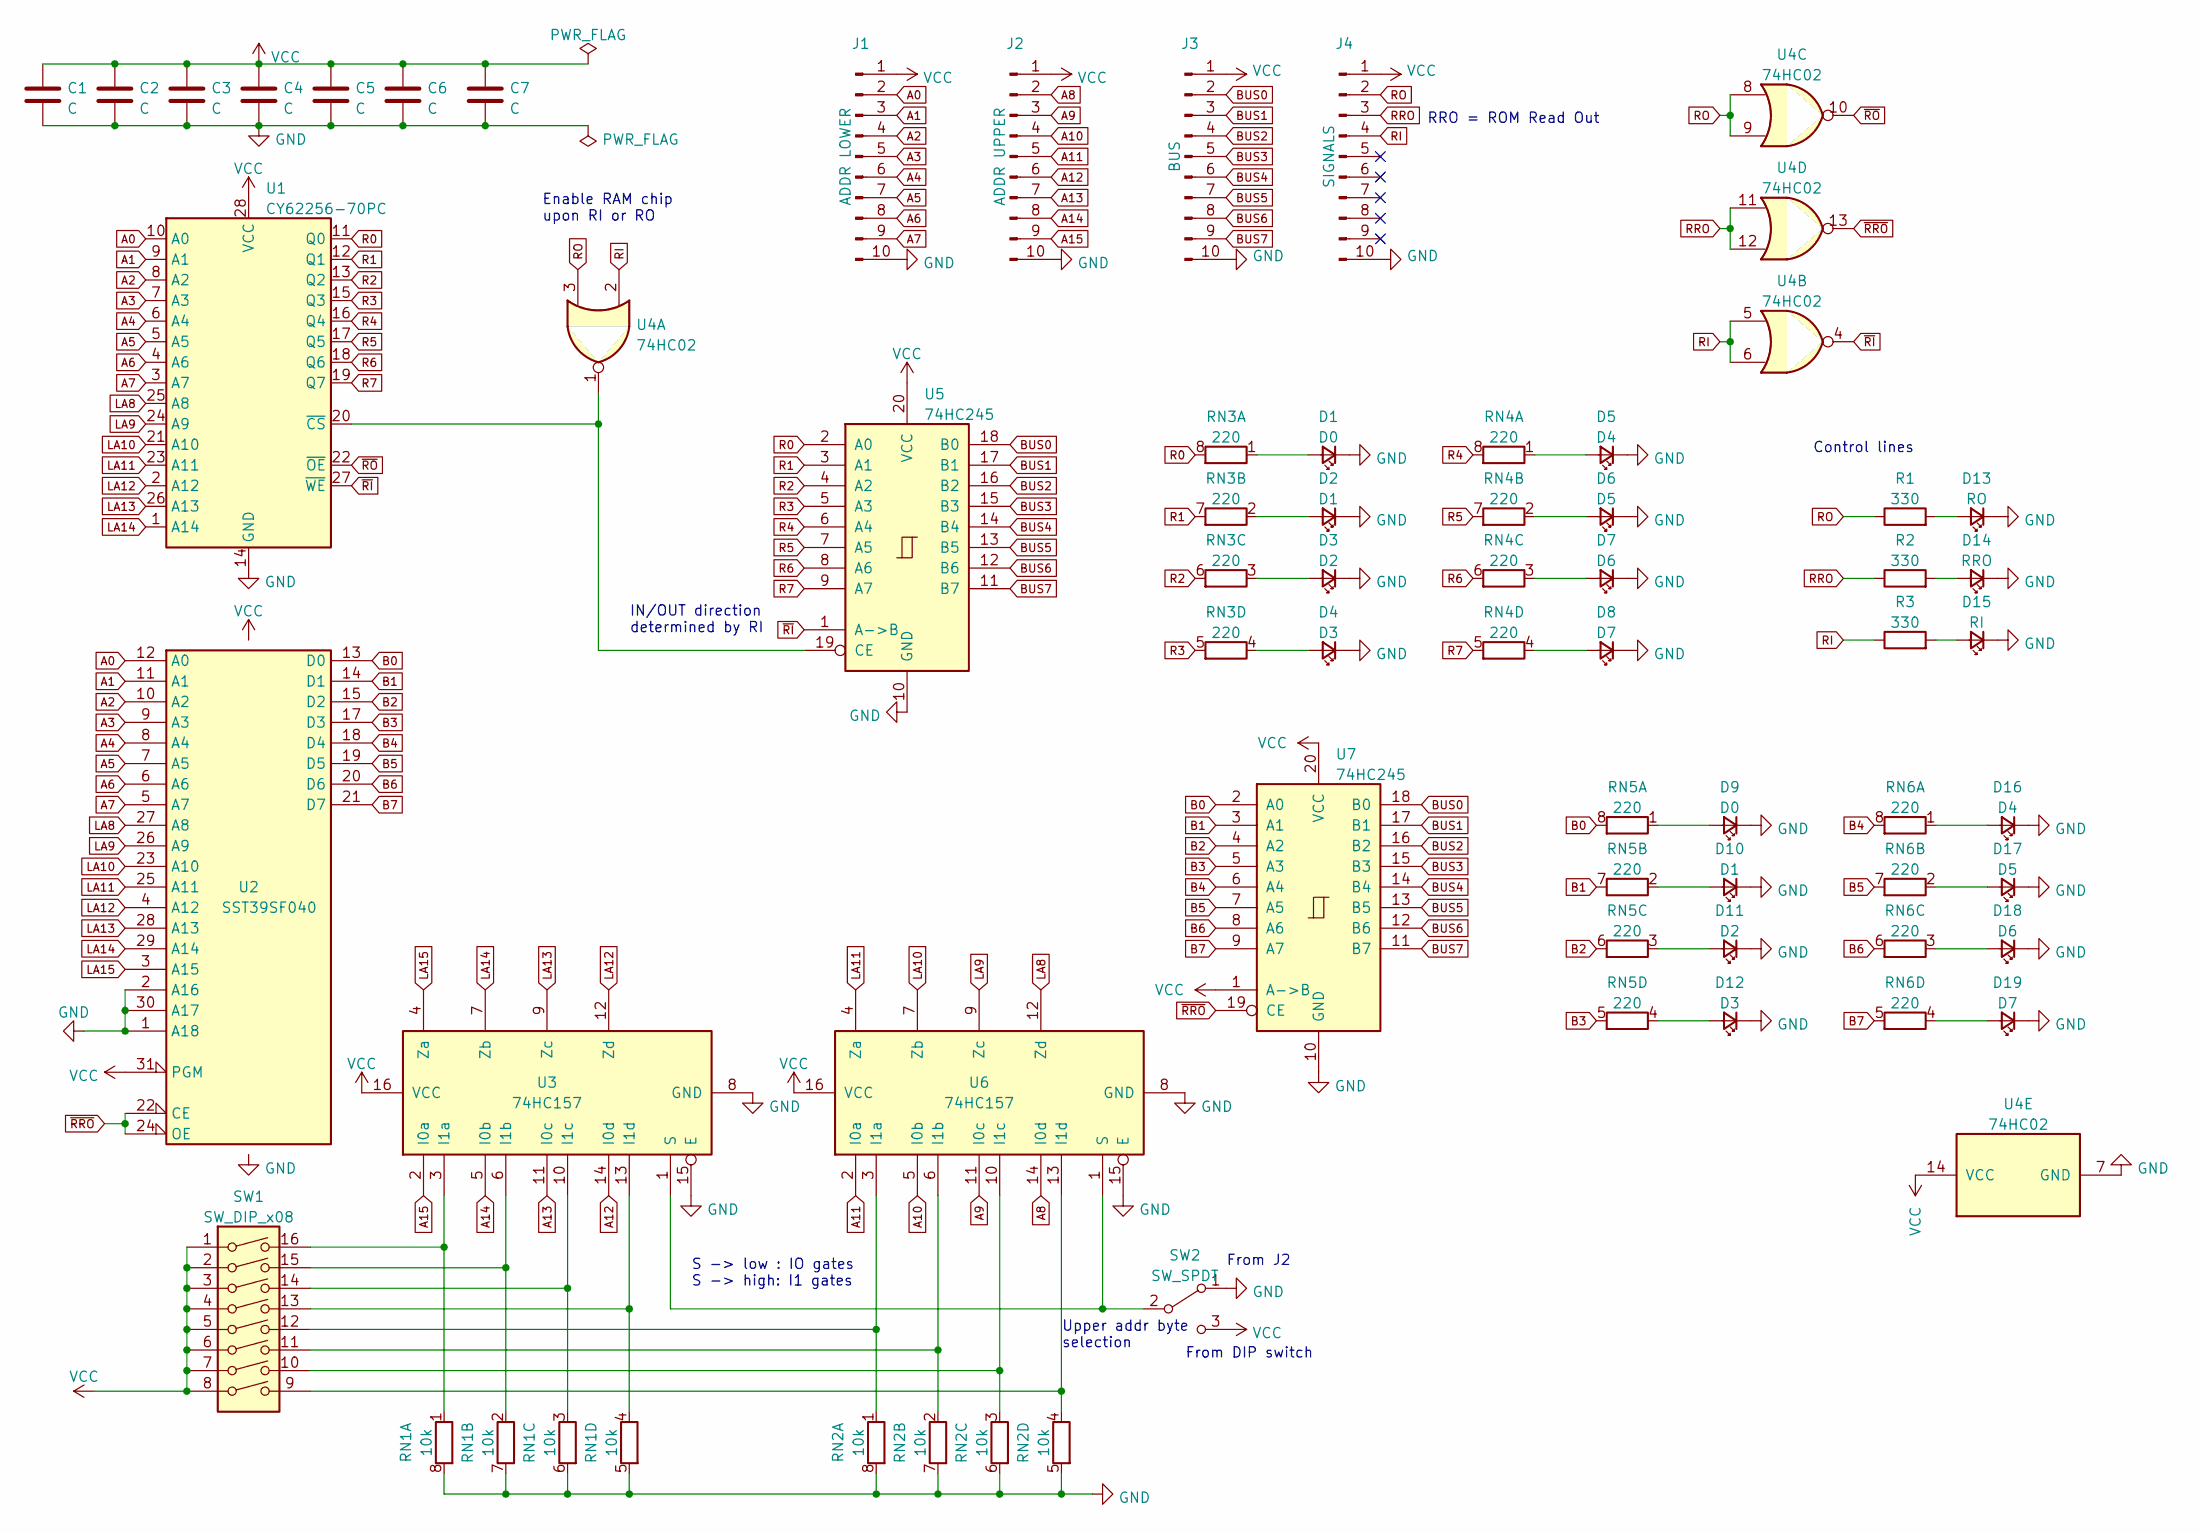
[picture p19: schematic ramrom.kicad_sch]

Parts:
C1, C2, C3, C4, C5, C6, C7: C; C_0805_2012Metric
D1, D9: D0; LED_0805_2012Metric
D2, D10: D1; LED_0805_2012Metric
D3, D11: D2; LED_0805_2012Metric
D4, D12: D3; LED_0805_2012Metric
D5, D16: D4; LED_0805_2012Metric
D6, D17: D5; LED_0805_2012Metric
D7, D18: D6; LED_0805_2012Metric
D8, D19: D7; LED_0805_2012Metric
D13: RO; LED_0805_2012Metric
D14: RRO; LED_0805_2012Metric
D15: RI; LED_0805_2012Metric
J1: ADDR LOWER; PinHeader_1x10_P2.54mm_Vertical
J2: ADDR UPPER; PinHeader_1x10_P2.54mm_Vertical
J3: BUS; PinHeader_1x10_P2.54mm_Vertical
J4: SIGNALS; PinHeader_1x10_P2.54mm_Vertical
R1, R2, R3: 330; R_0805_2012Metric
RN1, RN2: 10k; R_Array_Convex_4x0603
RN3, RN4, RN5, RN6: 220; R_Array_Convex_4x0603
SW1: SW_DIP_x08; SW_DIP_SPSTx08_Slide_6.7x21.88mm_W7.62mm_P2.54mm_LowProfile
SW2: SW_SPDT; SW_Slide_1P2T_CK_OS102011MS2Q
U1: CY62256-70PC; DIP-28_W15.24mm_Socket
U2: SST39SF040; DIP-32_W15.24mm_Socket
U3, U6: 74HC157; SO-16_3.9x9.9mm_P1.27mm
U4: 74HC02; SO-14_3.9x8.65mm_P1.27mm
U5, U7: 74HC245; SO-20_12.8x7.5mm_P1.27mm

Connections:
A0: J1.2, U1.10 (A0), U2.12 (A0)
A1: J1.3, U1.9 (A1), U2.11 (A1)
A2: J1.4, U1.8 (A2), U2.10 (A2)
A3: J1.5, U1.7 (A3), U2.9 (A3)
A4: J1.6, U1.6 (A4), U2.8 (A4)
A5: J1.7, U1.5 (A5), U2.7 (A5)
A6: J1.8, U1.4 (A6), U2.6 (A6)
A7: J1.9, U1.3 (A7), U2.5 (A7)
A8: J2.2, U6.14 (I0d)
A9: J2.3, U6.11 (I0c)
A10: J2.4, U6.5 (I0b)
A11: J2.5, U6.2 (I0a)
A12: J2.6, U3.14 (I0d)
A13: J2.7, U3.11 (I0c)
A14: J2.8, U3.5 (I0b)
A15: J2.9, U3.2 (I0a)
B0: RN5.8 (R1.2), U2.13 (D0), U7.2 (A0)
B1: RN5.7 (R2.2), U2.14 (D1), U7.3 (A1)
B2: RN5.6 (R3.2), U2.15 (D2), U7.4 (A2)
B3: RN5.5 (R4.2), U2.17 (D3), U7.5 (A3)
B4: RN6.8 (R1.2), U2.18 (D4), U7.6 (A4)
B5: RN6.7 (R2.2), U2.19 (D5), U7.7 (A5)
B6: RN6.6 (R3.2), U2.20 (D6), U7.8 (A6)
B7: RN6.5 (R4.2), U2.21 (D7), U7.9 (A7)
BUS0: J3.2, U5.18 (B0), U7.18 (B0)
BUS1: J3.3, U5.17 (B1), U7.17 (B1)
BUS2: J3.4, U5.16 (B2), U7.16 (B2)
BUS3: J3.5, U5.15 (B3), U7.15 (B3)
BUS4: J3.6, U5.14 (B4), U7.14 (B4)
BUS5: J3.7, U5.13 (B5), U7.13 (B5)
BUS6: J3.8, U5.12 (B6), U7.12 (B6)
BUS7: J3.9, U5.11 (B7), U7.11 (B7)
GND: C1.2, C2.2, C3.2, C4.2, C5.2, C6.2, C7.2, D1.1 (K), D2.1 (K), D3.1 (K), D4.1 (K), D5.1 (K), D6.1 (K), D7.1 (K), D8.1 (K), D9.1 (K), D10.1 (K), D11.1 (K), D12.1 (K), D13.1 (K), D14.1 (K), D15.1 (K), D16.1 (K), D17.1 (K), D18.1 (K), D19.1 (K), J1.10, J2.10, J3.10, J4.10, RN1.5 (R4.2), RN1.6 (R3.2), RN1.7 (R2.2), RN1.8 (R1.2), RN2.5 (R4.2), RN2.6 (R3.2), RN2.7 (R2.2), RN2.8 (R1.2), SW2.1 (A), U1.14 (GND), U2.1 (A18), U2.2 (A16), U2.16 (GND), U2.30 (A17), U3.8 (GND), U3.15 (E), U4.7 (GND), U5.10 (GND), U6.8 (GND), U6.15 (E), U7.10 (GND)
LA8: U1.25 (A8), U2.27 (A8), U6.12 (Zd)
LA9: U1.24 (A9), U2.26 (A9), U6.9 (Zc)
LA10: U1.21 (A10), U2.23 (A10), U6.7 (Zb)
LA11: U1.23 (A11), U2.25 (A11), U6.4 (Za)
LA12: U1.2 (A12), U2.4 (A12), U3.12 (Zd)
LA13: U1.26 (A13), U2.28 (A13), U3.9 (Zc)
LA14: U1.1 (A14), U2.29 (A14), U3.7 (Zb)
LA15: U2.3 (A15), U3.4 (Za)
unnamed: D1.2 (A), RN3.1 (R1.1)
unnamed: D2.2 (A), RN3.2 (R2.1)
unnamed: D3.2 (A), RN3.3 (R3.1)
unnamed: D4.2 (A), RN3.4 (R4.1)
unnamed: D5.2 (A), RN4.1 (R1.1)
unnamed: D6.2 (A), RN4.2 (R2.1)
unnamed: D7.2 (A), RN4.3 (R3.1)
unnamed: D8.2 (A), RN4.4 (R4.1)
unnamed: D9.2 (A), RN5.1 (R1.1)
unnamed: D10.2 (A), RN5.2 (R2.1)
unnamed: D11.2 (A), RN5.3 (R3.1)
unnamed: D12.2 (A), RN5.4 (R4.1)
unnamed: D13.2 (A), R1.2
unnamed: D14.2 (A), R2.2
unnamed: D15.2 (A), R3.2
unnamed: D16.2 (A), RN6.1 (R1.1)
unnamed: D17.2 (A), RN6.2 (R2.1)
unnamed: D18.2 (A), RN6.3 (R3.1)
unnamed: D19.2 (A), RN6.4 (R4.1)
unnamed: RN1.1 (R1.1), SW1.16, U3.3 (I1a)
unnamed: RN1.2 (R2.1), SW1.15, U3.6 (I1b)
unnamed: RN1.3 (R3.1), SW1.14, U3.10 (I1c)
unnamed: RN1.4 (R4.1), SW1.13, U3.13 (I1d)
unnamed: RN2.1 (R1.1), SW1.12, U6.3 (I1a)
unnamed: RN2.2 (R2.1), SW1.11, U6.6 (I1b)
unnamed: RN2.3 (R3.1), SW1.10, U6.10 (I1c)
unnamed: RN2.4 (R4.1), SW1.9, U6.13 (I1d)
unnamed: SW2.2 (B), U3.1 (S), U6.1 (S)
unnamed: U1.20 (~CS), U4.1, U5.19 (CE)
R0: RN3.8 (R1.2), U1.11 (Q0), U5.2 (A0)
R1: RN3.7 (R2.2), U1.12 (Q1), U5.3 (A1)
R2: RN3.6 (R3.2), U1.13 (Q2), U5.4 (A2)
R3: RN3.5 (R4.2), U1.15 (Q3), U5.5 (A3)
R4: RN4.8 (R1.2), U1.16 (Q4), U5.6 (A4)
R5: RN4.7 (R2.2), U1.17 (Q5), U5.7 (A5)
R6: RN4.6 (R3.2), U1.18 (Q6), U5.8 (A6)
R7: RN4.5 (R4.2), U1.19 (Q7), U5.9 (A7)
RI: J4.4, R3.1, U4.2, U4.5, U4.6
RO: J4.2, R1.1, U4.3, U4.8, U4.9
RRO: J4.3, R2.1, U4.11, U4.12
VCC: C1.1, C2.1, C3.1, C4.1, C5.1, C6.1, C7.1, J1.1, J2.1, J3.1, J4.1, SW1.1, SW1.2, SW1.3, SW1.4, SW1.5, SW1.6, SW1.7, SW1.8, SW2.3 (C), U1.28 (VCC), U2.31 (PGM), U2.32 (VCC), U3.16 (VCC), U4.14 (VCC), U5.20 (VCC), U6.16 (VCC), U7.1 (A->B), U7.20 (VCC)
~RI: U1.27 (~WE), U4.4, U5.1 (A->B)
~RO: U1.22 (~OE), U4.10
~RRO: U2.22 (CE), U2.24 (OE), U4.13, U7.19 (CE)

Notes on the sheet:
Upper addr byte selection
From J2
Control lines
From DIP switch
Enable RAM chip upon RI or RO
S -> low : IO gates S -> high: I1 gates
IN/OUT direction determined by RI
RRO = ROM Read Out

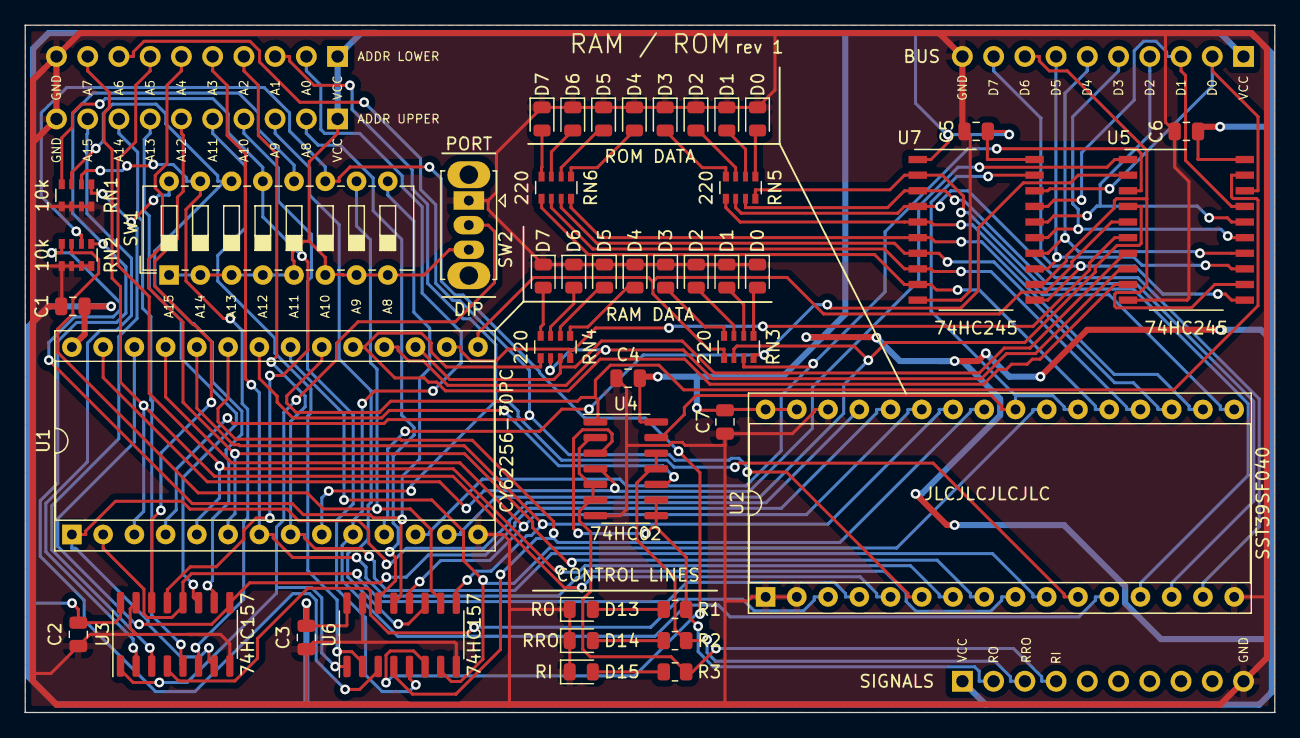
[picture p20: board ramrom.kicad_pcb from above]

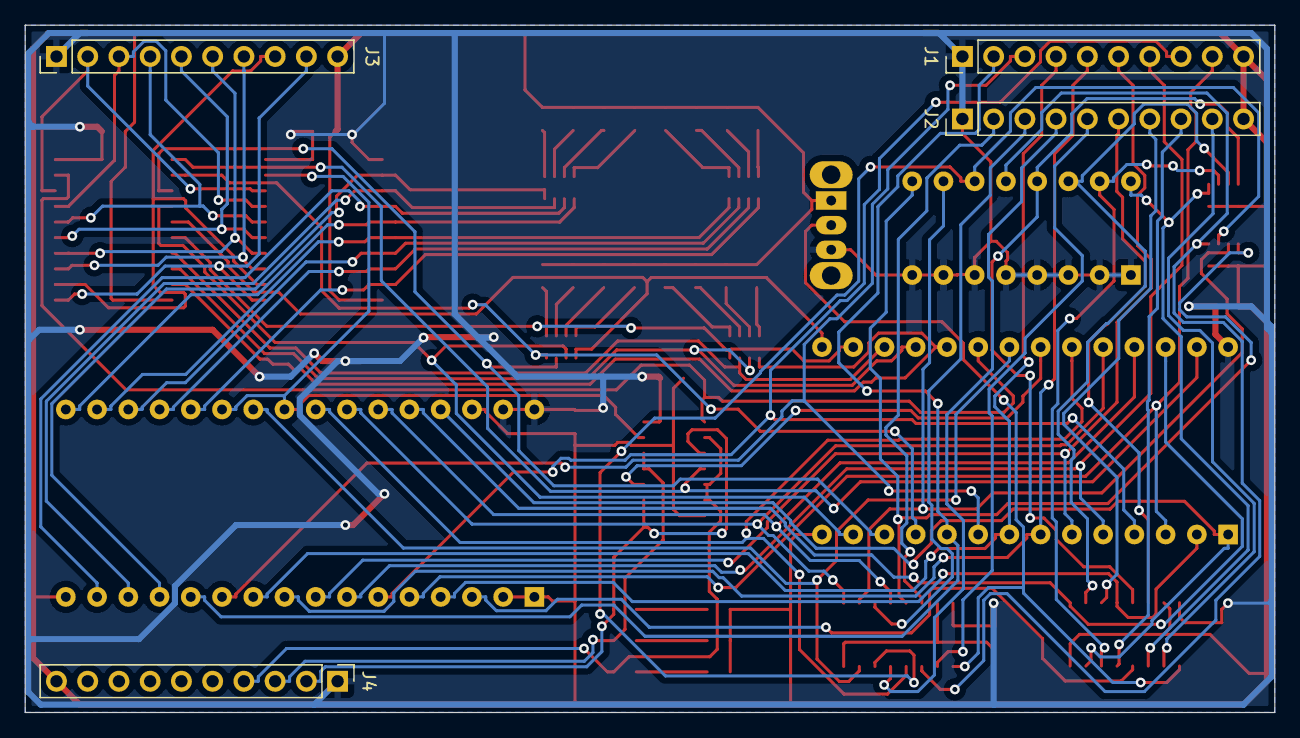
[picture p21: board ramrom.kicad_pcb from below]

Board: 2 copper layers, 101.6 x 55.9 mm, 48 parts (4 on the bottom side), 85 nets.

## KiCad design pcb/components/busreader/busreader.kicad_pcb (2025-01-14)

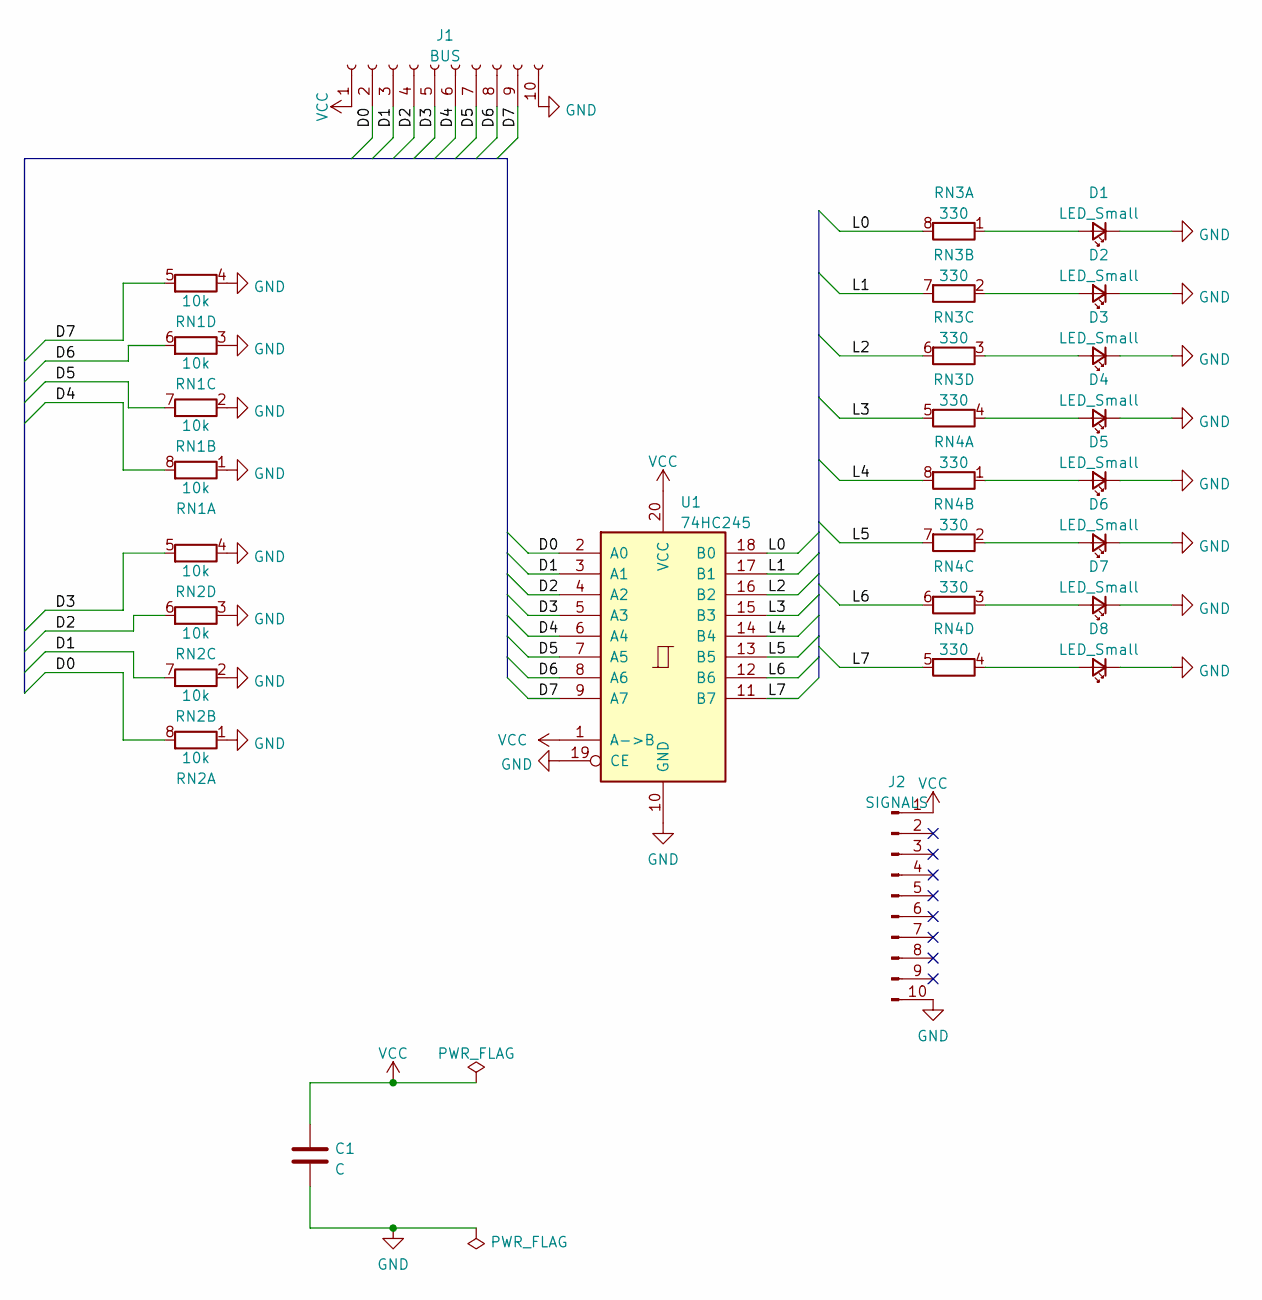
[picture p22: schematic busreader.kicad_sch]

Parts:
C1: C; C_0805_2012Metric
D1, D2, D3, D4, D5, D6, D7, D8: LED_Small; LED_0805_2012Metric
J1: BUS; PinHeader_1x10_P2.54mm_Vertical
J2: SIGNALS; PinHeader_1x10_P2.54mm_Vertical
RN1, RN2: 10k; R_Array_Convex_4x0603
RN3, RN4: 330; R_Array_Convex_4x0603
U1: 74HC245; SOIC-20W_7.5x12.8mm_P1.27mm

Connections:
/D0: J1.2, RN2.8 (R1.2), U1.2 (A0)
/D1: J1.3, RN2.7 (R2.2), U1.3 (A1)
/D2: J1.4, RN2.6 (R3.2), U1.4 (A2)
/D3: J1.5, RN2.5 (R4.2), U1.5 (A3)
/D4: J1.6, RN1.8 (R1.2), U1.6 (A4)
/D5: J1.7, RN1.7 (R2.2), U1.7 (A5)
/D6: J1.8, RN1.6 (R3.2), U1.8 (A6)
/D7: J1.9, RN1.5 (R4.2), U1.9 (A7)
/L0: RN3.8 (R1.2), U1.18 (B0)
/L1: RN3.7 (R2.2), U1.17 (B1)
/L2: RN3.6 (R3.2), U1.16 (B2)
/L3: RN3.5 (R4.2), U1.15 (B3)
/L4: RN4.8 (R1.2), U1.14 (B4)
/L5: RN4.7 (R2.2), U1.13 (B5)
/L6: RN4.6 (R3.2), U1.12 (B6)
/L7: RN4.5 (R4.2), U1.11 (B7)
GND: C1.2, D1.1 (K), D2.1 (K), D3.1 (K), D4.1 (K), D5.1 (K), D6.1 (K), D7.1 (K), D8.1 (K), J1.10, J2.10, RN1.1 (R1.1), RN1.2 (R2.1), RN1.3 (R3.1), RN1.4 (R4.1), RN2.1 (R1.1), RN2.2 (R2.1), RN2.3 (R3.1), RN2.4 (R4.1), U1.10 (GND), U1.19 (CE)
unnamed: D1.2 (A), RN3.1 (R1.1)
unnamed: D2.2 (A), RN3.2 (R2.1)
unnamed: D3.2 (A), RN3.3 (R3.1)
unnamed: D4.2 (A), RN3.4 (R4.1)
unnamed: D5.2 (A), RN4.1 (R1.1)
unnamed: D6.2 (A), RN4.2 (R2.1)
unnamed: D7.2 (A), RN4.3 (R3.1)
unnamed: D8.2 (A), RN4.4 (R4.1)
VCC: C1.1, J1.1, J2.1, U1.1 (A->B), U1.20 (VCC)

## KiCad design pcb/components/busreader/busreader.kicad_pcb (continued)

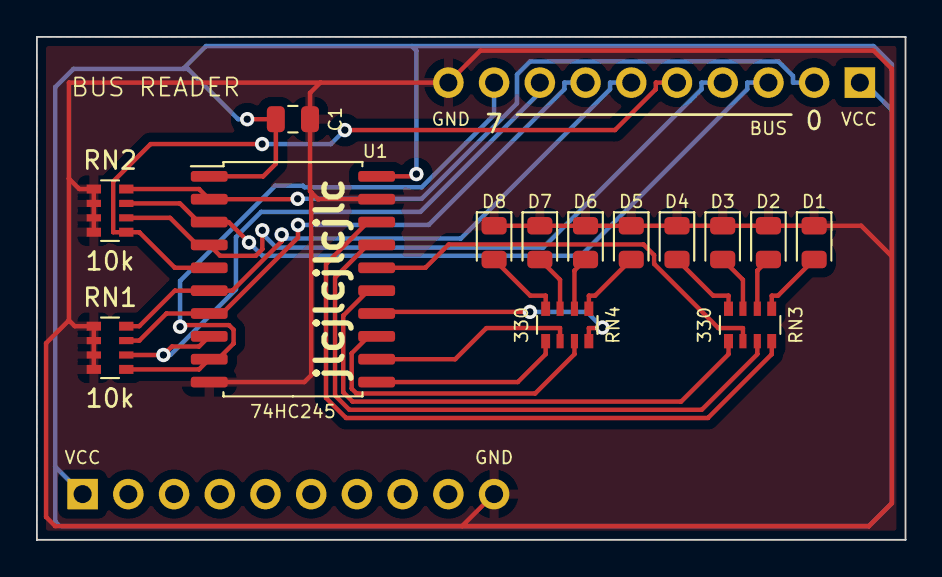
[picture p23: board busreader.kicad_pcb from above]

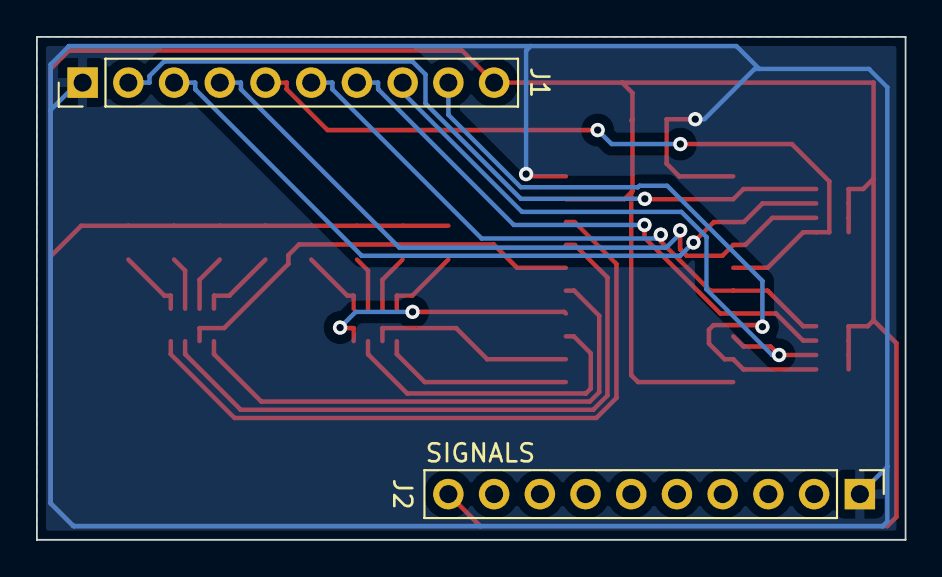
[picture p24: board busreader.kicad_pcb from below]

Board: 2 copper layers, 48.3 x 27.9 mm, 16 parts (2 on the bottom side), 26 nets.

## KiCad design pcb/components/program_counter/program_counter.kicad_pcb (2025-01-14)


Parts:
C1, C2, C3, C4: C; C_0805_2012Metric
D1, D2, D3, D4, D5, D6, D7, D8: LED_Small; LED_0805_2012Metric
D9: CE; LED_0805_2012Metric
D10: J; LED_0805_2012Metric
D11: CO; LED_0805_2012Metric
J1: BUS; PinHeader_1x10_P2.54mm_Vertical
J2: SIGNALS; PinHeader_1x10_P2.54mm_Vertical
R1, R2, R3: 330; R_0805_2012Metric
RN1, RN2: 220; R_Array_Convex_4x0603
U1, U2: 74HC161; SO-16_3.9x9.9mm_P1.27mm
U3: 74HC245; SOIC-20W_7.5x12.8mm_P1.27mm
U4: 74HC00; SO-14_3.9x8.65mm_P1.27mm

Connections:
/D0: J1.2, U2.3 (D0), U3.18 (B0)
/D1: J1.3, U2.4 (D1), U3.17 (B1)
/D2: J1.4, U2.5 (D2), U3.16 (B2)
/D3: J1.5, U2.6 (D3), U3.15 (B3)
/D4: J1.6, U1.3 (D0), U3.14 (B4)
/D5: J1.7, U1.4 (D1), U3.13 (B5)
/D6: J1.8, U1.5 (D2), U3.12 (B6)
/D7: J1.9, U1.6 (D3), U3.11 (B7)
/L0: RN1.8 (R1.2), U2.14 (Q0), U3.2 (A0)
/L1: RN1.7 (R2.2), U2.13 (Q1), U3.3 (A1)
/L2: RN1.6 (R3.2), U2.12 (Q2), U3.4 (A2)
/L3: RN1.5 (R4.2), U2.11 (Q3), U3.5 (A3)
/L4: RN2.8 (R1.2), U1.14 (Q0), U3.6 (A4)
/L5: RN2.7 (R2.2), U1.13 (Q1), U3.7 (A5)
/L6: RN2.6 (R3.2), U1.12 (Q2), U3.8 (A6)
/L7: RN2.5 (R4.2), U1.11 (Q3), U3.9 (A7)
CE: J2.6, R1.1, U2.7 (CEP), U2.10 (CET)
CLK: J2.2, U1.2 (CP), U2.2 (CP)
CO: J2.5, R3.1, U4.4, U4.5
GND: C1.2, C2.2, C3.2, C4.2, D1.1 (K), D2.1 (K), D3.1 (K), D4.1 (K), D5.1 (K), D6.1 (K), D7.1 (K), D8.1 (K), D9.1 (K), D10.1 (K), D11.1 (K), J1.10, J2.10, U1.8 (GND), U2.8 (GND), U3.10 (GND), U4.7 (GND)
J: J2.3, R2.1, U4.1, U4.2
unnamed: D1.2 (A), RN1.1 (R1.1)
unnamed: D2.2 (A), RN1.2 (R2.1)
unnamed: D3.2 (A), RN1.3 (R3.1)
unnamed: D4.2 (A), RN1.4 (R4.1)
unnamed: D5.2 (A), RN2.1 (R1.1)
unnamed: D6.2 (A), RN2.2 (R2.1)
unnamed: D7.2 (A), RN2.3 (R3.1)
unnamed: D8.2 (A), RN2.4 (R4.1)
unnamed: D9.2 (A), R1.2
unnamed: D10.2 (A), R2.2
unnamed: D11.2 (A), R3.2
unnamed: U1.10 (CET), U2.15 (TC)
VCC: C1.1, C2.1, C3.1, C4.1, J1.1, J2.1, U1.7 (CEP), U1.16 (VCC), U2.16 (VCC), U3.1 (A->B), U3.20 (VCC), U4.9, U4.10, U4.12, U4.13, U4.14 (VCC)
~CLR: J2.4, U1.1 (~MR), U2.1 (~MR)
~CO: U3.19 (CE), U4.6
~J: U1.9 (~PE), U2.9 (~PE), U4.3



Board: 2 copper layers, 101.6 x 27.9 mm, 26 parts (2 on the bottom side), 37 nets.

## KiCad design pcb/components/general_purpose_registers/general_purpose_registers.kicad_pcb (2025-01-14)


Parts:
C1, C2, C3: C; C_0805_2012Metric
D1, D2, D3, D4, D5, D6, D7, D8: LED_Small; LED_0805_2012Metric
D9: IN; LED_0805_2012Metric
D10: OUT; LED_0805_2012Metric
J1: LOCAL; PinHeader_1x10_P2.54mm_Vertical
J2: BUS; PinHeader_1x10_P2.54mm_Vertical
J3: SIGNALS; PinHeader_1x10_P2.54mm_Vertical
R1, R2: 330; R_0805_2012Metric
RN1, RN2: 220; R_Array_Convex_4x0603
U1: 74HC00; SO-14_3.9x8.65mm_P1.27mm
U2: 74HC273; SOIC-20W_7.5x12.8mm_P1.27mm
U3: 74HC245; SOIC-20W_7.5x12.8mm_P1.27mm

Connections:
/D0: J2.2, U2.3 (D0), U3.18 (B0)
/D1: J2.3, U2.4 (D1), U3.17 (B1)
/D2: J2.4, U2.7 (D2), U3.16 (B2)
/D3: J2.5, U2.8 (D3), U3.15 (B3)
/D4: J2.6, U2.13 (D4), U3.14 (B4)
/D5: J2.7, U2.14 (D5), U3.13 (B5)
/D6: J2.8, U2.17 (D6), U3.12 (B6)
/D7: J2.9, U2.18 (D7), U3.11 (B7)
/L0: J1.2, RN1.8 (R1.2), U2.2 (Q0), U3.2 (A0)
/L1: J1.3, RN1.7 (R2.2), U2.5 (Q1), U3.3 (A1)
/L2: J1.4, RN1.6 (R3.2), U2.6 (Q2), U3.4 (A2)
/L3: J1.5, RN1.5 (R4.2), U2.9 (Q3), U3.5 (A3)
/L4: J1.6, RN2.8 (R1.2), U2.12 (Q4), U3.6 (A4)
/L5: J1.7, RN2.7 (R2.2), U2.15 (Q5), U3.7 (A5)
/L6: J1.8, RN2.6 (R3.2), U2.16 (Q6), U3.8 (A6)
/L7: J1.9, RN2.5 (R4.2), U2.19 (Q7), U3.9 (A7)
CLK: J3.2, U1.1
GND: C1.2, C2.2, C3.2, D1.1 (K), D2.1 (K), D3.1 (K), D4.1 (K), D5.1 (K), D6.1 (K), D7.1 (K), D8.1 (K), D9.1 (K), D10.1 (K), J1.10, J2.10, J3.10, U1.7 (GND), U1.12, U1.13, U2.10 (GND), U3.10 (GND)
IN: J3.3, R1.1, U1.2
unnamed: D1.2 (A), RN1.1 (R1.1)
unnamed: D2.2 (A), RN1.2 (R2.1)
unnamed: D3.2 (A), RN1.3 (R3.1)
unnamed: D4.2 (A), RN1.4 (R4.1)
unnamed: D5.2 (A), RN2.1 (R1.1)
unnamed: D6.2 (A), RN2.2 (R2.1)
unnamed: D7.2 (A), RN2.3 (R3.1)
unnamed: D8.2 (A), RN2.4 (R4.1)
unnamed: D9.2 (A), R1.2
unnamed: D10.2 (A), R2.2
unnamed: U1.3, U1.4, U1.5
unnamed: U1.6, U2.11 (Cp)
unnamed: U1.8, U3.19 (CE)
OUT: J3.5, R2.1, U1.9, U1.10
VCC: C1.1, C2.1, C3.1, J1.1, J2.1, J3.1, U1.14 (VCC), U2.20 (VCC), U3.1 (A->B), U3.20 (VCC)
~CLR: J3.4, U2.1 (~Mr)



Board: 2 copper layers, 101.6 x 27.9 mm, 23 parts (3 on the bottom side), 35 nets.

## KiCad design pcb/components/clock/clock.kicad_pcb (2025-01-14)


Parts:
C1, C6: 0.01uF; C_0805_2012Metric_Pad1.18x1.45mm_HandSolder
C2: 15pF; C_0805_2012Metric_Pad1.18x1.45mm_HandSolder
C3, C7, C8, C9, C10, C11, C12, C13, C14, C15, C16, C17, C18, C19, C20: 0.1uF; C_0805_2012Metric_Pad1.18x1.45mm_HandSolder
C4: .1uF; C_0805_2012Metric_Pad1.18x1.45mm_HandSolder
C5: 1uF; C_0805_2012Metric_Pad1.18x1.45mm_HandSolder
D1: CLK; LED_0805_2012Metric_Pad1.15x1.40mm_HandSolder
D2: S0; LED_0805_2012Metric_Pad1.15x1.40mm_HandSolder
D3: S1; LED_0805_2012Metric_Pad1.15x1.40mm_HandSolder
D4: S2; LED_0805_2012Metric_Pad1.15x1.40mm_HandSolder
D5: ~{CLR}; LED_0805_2012Metric_Pad1.15x1.40mm_HandSolder
D6: CD0; LED_0805_2012Metric_Pad1.15x1.40mm_HandSolder
D7: CD1; LED_0805_2012Metric_Pad1.15x1.40mm_HandSolder
D8: CD2; LED_0805_2012Metric_Pad1.15x1.40mm_HandSolder
D9: CD3; LED_0805_2012Metric_Pad1.15x1.40mm_HandSolder
D10: MANHALT; LED_0805_2012Metric_Pad1.15x1.40mm_HandSolder
D11: HALT; LED_0805_2012Metric_Pad1.15x1.40mm_HandSolder
J1: SIGNALS; PinHeader_1x10_P2.54mm_Vertical
J2: X; PinHeader_1x10_P2.54mm_Vertical
R1, R4, R5, R6, R10, R11: 10k; R_0805_2012Metric_Pad1.20x1.40mm_HandSolder
R2, R3: 1k; R_0805_2012Metric_Pad1.20x1.40mm_HandSolder
R7, R9, R12, R13: 330; R_0805_2012Metric_Pad1.20x1.40mm_HandSolder
R8: 1M; R_0805_2012Metric_Pad1.20x1.40mm_HandSolder
RN1, RN3: 10k; R_Array_Convex_4x0603
RN2, RN4: 220; R_Array_Convex_4x0603
RV1: 1M; Potentiometer_ACP_CA9-V10_Vertical
SW1: SWS0; SW_PUSH_6mm
SW2: Clock Divider; SW_DIP_SPSTx04_Slide_6.7x11.72mm_W8.61mm_P2.54mm_LowProfile
SW3: SWS1; SW_PUSH_6mm
SW4: MANCLK; SW_PUSH-12mm_Wuerth-430476085716
SW5: SWS2; SW_PUSH_6mm
SW6: Reset Counter; SW_DIP_SPSTx04_Slide_6.7x11.72mm_W8.61mm_P2.54mm_LowProfile
SW7: CLEAR; SW_PUSH_6mm
SW8: MANHALT; tactile_button
U1, U9: SE555; SOIC-8_3.9x4.9mm_P1.27mm
U2, U5, U8, U11: 74HC00; SO-14_3.9x8.65mm_P1.27mm
U3: 74HC14; SO-14_3.9x8.65mm_P1.27mm
U4: 74HC151; SO-16_3.9x9.9mm_P1.27mm
U6: 74HC02; SO-14_3.9x8.65mm_P1.27mm
U7, U10, U12: 74HC193; SO-16_3.9x9.9mm_P1.27mm
X1: TCXO-14; Oscillator_DIP-14

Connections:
CLK: J1.2, U3.4
CLKSRC1: U4.3 (I1), U9.3 (Q)
CLKSRC2: U1.3 (Q), U4.2 (I2)
CLKSRC3: U4.15 (I4), U10.3 (QA)
CS0: RN2.8 (R1.2), U2.3, U2.9, U4.11 (S0)
CS1: RN2.7 (R2.2), U4.10 (S1), U5.3, U5.9
CS2: RN2.6 (R3.2), U4.9 (S2), U8.3, U8.9
GND: C1.2, C2.1, C3.2, C4.1, C5.2, C6.2, C7.2, C8.1, C9.1, C10.1, C11.1, C12.1, C13.1, C14.1, C15.1, C16.2, C17.1, C18.1, C19.1, C20.1, D2.1 (K), D3.1 (K), D4.1 (K), D6.1 (K), D7.1 (K), D8.1 (K), D9.1 (K), J1.10, J2.10, R7.2, R9.1, R11.1, R12.2, R13.2, RN1.5 (R4.2), RN1.6 (R3.2), RN1.7 (R2.2), RN1.8 (R1.2), RN3.5 (R4.2), RN3.6 (R3.2), RN3.7 (R2.2), RN3.8 (R1.2), SW1.1, SW3.1, SW4.1, SW5.1, SW7.1, U1.1 (GND), U2.7 (GND), U3.7 (GND), U4.1 (I3), U4.4 (I0), U4.8 (GND), U4.12 (I7), U4.13 (I6), U4.14 (I5), U5.7 (GND), U6.7 (GND), U7.8 (GND), U7.14 (CLR), U8.7 (GND), U9.1 (GND), U10.8 (GND), U10.14 (CLR), U11.7 (GND), U12.8 (GND), U12.14 (CLR), X1.7 (GND)
HALTLED: D11.2 (A), U6.10
HLT: J1.4, U6.3
MANHLT: D10.2 (A), R11.2, SW8.1, U6.2
unnamed: C1.1, U1.5 (CV)
unnamed: C2.2, U7.4 (DOWN), X1.8 (OUT)
unnamed: C3.1, R1.1, SW1.2, U2.1, U5.12, U8.13
unnamed: C5.1, RV1.1, U1.2 (TR), U1.6 (THR)
unnamed: C6.1, U9.5 (CV)
unnamed: C7.1, R8.2, U9.6 (THR), U9.7 (DIS)
unnamed: C16.1, R10.1, SW7.2, U11.1, U12.11 (~LOAD)
unnamed: D1.1 (K), R7.1
unnamed: D1.2 (A), U3.10
unnamed: D2.2 (A), RN2.1 (R1.1)
unnamed: D3.2 (A), RN2.2 (R2.1)
unnamed: D4.2 (A), RN2.3 (R3.1)
unnamed: D5.1 (K), R9.2
unnamed: D5.2 (A), U11.3, U11.9, U11.13, U12.5 (UP)
unnamed: D6.2 (A), RN4.1 (R1.1)
unnamed: D7.2 (A), RN4.2 (R2.1)
unnamed: D8.2 (A), RN4.3 (R3.1)
unnamed: D9.2 (A), RN4.4 (R4.1)
unnamed: D10.1 (K), R12.1
unnamed: D11.1 (K), R13.1
unnamed: R2.2, R3.1, U1.7 (DIS)
unnamed: R3.2, RV1.2
unnamed: R4.1, SW3.2, U2.12, U5.1, U8.12
unnamed: R5.1, SW4.2, U9.2 (TR)
unnamed: R6.1, SW5.2, U2.13, U5.13, U8.1
unnamed: RN1.1 (R1.1), SW2.8, U7.9 (D)
unnamed: RN1.2 (R2.1), SW2.7, U7.10 (C)
unnamed: RN1.3 (R3.1), SW2.6, U7.1 (B)
unnamed: RN1.4 (R4.1), SW2.5, U7.15 (A)
unnamed: RN3.1 (R1.1), SW6.8, U12.9 (D)
unnamed: RN3.2 (R2.1), SW6.7, U12.10 (C)
unnamed: RN3.3 (R3.1), SW6.6, U12.1 (B)
unnamed: RN3.4 (R4.1), SW6.5, U12.15 (A)
unnamed: RN4.5 (R4.2), U12.7 (QD)
unnamed: RN4.6 (R3.2), U12.6 (QC)
unnamed: RN4.7 (R2.2), U12.2 (QB)
unnamed: RN4.8 (R1.2), U12.3 (QA)
unnamed: U2.2, U2.8
unnamed: U2.6, U2.10
unnamed: U2.4, U2.5, U2.11
unnamed: U3.2, U3.3
unnamed: U3.6, U3.11
unnamed: U4.7 (~E), U6.4
unnamed: U5.2, U5.8
unnamed: U5.6, U5.10
unnamed: U5.4, U5.5, U5.11
unnamed: U8.2, U8.8
unnamed: U8.6, U8.10
unnamed: U8.4, U8.5, U8.11
unnamed: U7.11 (~LOAD), U7.13 (~BO), U10.5 (UP)
unnamed: U11.6, U12.4 (DOWN)
unnamed: U11.10, U12.13 (~BO)
unnamed: U11.4, U11.5, U11.11
RAWCLK: U3.1, U3.5, U4.5 (Z), U11.12
VCC: C4.2, C8.2, C9.2, C10.2, C11.2, C12.2, C13.2, C14.2, C15.2, C17.2, C18.2, C19.2, C20.2, J1.1, J2.1, R1.2, R2.1, R4.2, R5.2, R6.2, R8.1, R10.2, SW2.1, SW2.2, SW2.3, SW2.4, SW6.1, SW6.2, SW6.3, SW6.4, SW8.2, U1.4 (R), U1.8 (VCC), U2.14 (VCC), U3.9, U3.13, U3.14 (VCC), U4.16 (VCC), U5.14 (VCC), U6.11, U6.12, U6.14 (VCC), U7.5 (UP), U7.16 (VCC), U8.14 (VCC), U9.4 (R), U9.8 (VCC), U10.4 (DOWN), U10.11 (~LOAD), U10.16 (VCC), U11.14 (VCC), U12.16 (VCC), X1.14 (Vcc)
~CLR: J1.3, U11.2, U11.8
~HALT: U6.1, U6.5, U6.6, U6.8, U6.9

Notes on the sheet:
Unused ports
Manual HALT
Ensure S0 is selected upon power-up
Slow Oscillator
Interface ports
POWER/GROUND Rails
BTNCS1
BTNCS2
Clock Divider Circuit
Clock selector
Manual Single Step Button
BTNCS0
Clear circuit



Board: 2 copper layers, 101.6 x 55.9 mm, 72 parts (2 on the bottom side), 68 nets.

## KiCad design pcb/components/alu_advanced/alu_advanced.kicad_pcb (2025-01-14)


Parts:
C1, C2, C3, C4, C5, C6, C7, C8, C9: C; C_0805_2012Metric
D1: R0; LED_0805_2012Metric
D2: R1; LED_0805_2012Metric
D3: R2; LED_0805_2012Metric
D4: R3; LED_0805_2012Metric
D5: CF; LED_0805_2012Metric
D6: ZF; LED_0805_2012Metric
D7: SU; LED_0805_2012Metric
D8: FI; LED_0805_2012Metric
D9: EO; LED_0805_2012Metric
D10: R4; LED_0805_2012Metric
D11: R5; LED_0805_2012Metric
D12: R6; LED_0805_2012Metric
D13: R7; LED_0805_2012Metric
J1: A; PinHeader_1x10_P2.54mm_Vertical
J2: B; PinHeader_1x10_P2.54mm_Vertical
J3: BUS; PinHeader_1x10_P2.54mm_Vertical
J4: SIGNALS; PinHeader_1x10_P2.54mm_Vertical
J5: LU; PinHeader_1x10_P2.54mm_Vertical
R1, R2: 220; R_0805_2012Metric
R3, R4, R5: 330; R_0805_2012Metric
RN1, RN2: 220; R_Array_Convex_4x0603
U1: 74HC02; SO-14_3.9x8.65mm_P1.27mm
U2: 74HC08; SO-14_3.9x8.65mm_P1.27mm
U3, U4: 74HC283; SO-16_3.9x9.9mm_P1.27mm
U5: 74HC00; SO-14_3.9x8.65mm_P1.27mm
U6, U8: 74HC157; SO-16_3.9x9.9mm_P1.27mm
U7: 74HC245; SO-20_12.8x7.5mm_P1.27mm
U9: 74HC173; SO-16_3.9x9.9mm_P1.27mm

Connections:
A0: J1.2; also elsewhere on the board
A1: J1.3; also elsewhere on the board
A2: J1.4; also elsewhere on the board
A3: J1.5; also elsewhere on the board
A4: J1.6; also elsewhere on the board
A5: J1.7; also elsewhere on the board
A6: J1.8; also elsewhere on the board
A7: J1.9; also elsewhere on the board
B0: J2.9; also elsewhere on the board
B1: J2.8; also elsewhere on the board
B2: J2.7; also elsewhere on the board
B3: J2.6; also elsewhere on the board
B4: J2.5; also elsewhere on the board
B5: J2.4; also elsewhere on the board
B6: J2.3; also elsewhere on the board
B7: J2.2; also elsewhere on the board
BUS0: J3.2, U7.11 (B7)
BUS1: J3.3, U7.12 (B6)
BUS2: J3.4, U7.13 (B5)
BUS3: J3.5, U7.14 (B4)
BUS4: J3.6, U7.15 (B3)
BUS5: J3.7, U7.16 (B2)
BUS6: J3.8, U7.17 (B1)
BUS7: J3.9, U7.18 (B0)
CF: J4.7, R1.1, U9.3 (Q0)
CFS: U2.12, U3.9 (C4)
CLK: J4.2, U9.7 (Cp)
CLR: U5.6, U9.15 (Mr)
EO: J4.6, R5.1, U5.9, U5.10
FI: J4.3, R4.1, U5.1, U5.2
G0: U4.6 (B1); also elsewhere on the board
G1: U4.2 (B2), U6.2 (I0a); also elsewhere on the board
G2: U4.15 (B3), U6.5 (I0b); also elsewhere on the board
G3: U4.11 (B4), U6.11 (I0c); also elsewhere on the board
G4: U3.6 (B1), U6.14 (I0d); also elsewhere on the board
G5: U3.2 (B2), U8.2 (I0a); also elsewhere on the board
G6: U3.15 (B3), U8.5 (I0b); also elsewhere on the board
G7: U3.11 (B4), U8.11 (I0c); also elsewhere on the board
GND: C1.2, C2.2, C3.2, C4.2, C5.2, C6.2, C7.2, C8.2, C9.2, D1.1 (K), D2.1 (K), D3.1 (K), D4.1 (K), D5.1 (K), D6.1 (K), D7.1 (K), D8.1 (K), D9.1 (K), D10.1 (K), D11.1 (K), D12.1 (K), D13.1 (K), J1.10, J2.10, J3.10, J4.10, J5.10, U1.7 (GND), U2.7 (GND), U3.8 (GND), U4.8 (GND), U5.7 (GND), U6.8 (GND), U6.15 (E), U7.10 (GND), U8.8 (GND), U8.14 (I0d), U8.15 (E), U9.1 (Oe1), U9.2 (Oe2), U9.8 (GND), U9.11 (D3), U9.12 (D2); also elsewhere on the board
IG0: J5.6; also elsewhere on the board
IG1: J5.7; also elsewhere on the board
IG2: J5.8; also elsewhere on the board
IG3: J5.9; also elsewhere on the board
IP0: J5.2; also elsewhere on the board
IP1: J5.3; also elsewhere on the board
IP2: J5.4; also elsewhere on the board
IP3: J5.5; also elsewhere on the board
unnamed: D1.2 (A), RN1.1 (R1.1)
unnamed: D2.2 (A), RN1.2 (R2.1)
unnamed: D3.2 (A), RN1.3 (R3.1)
unnamed: D4.2 (A), RN1.4 (R4.1)
unnamed: D5.2 (A), R1.2
unnamed: D6.2 (A), R2.2
unnamed: D7.2 (A), R3.2
unnamed: D8.2 (A), R4.2
unnamed: D9.2 (A), R5.2
unnamed: D10.2 (A), RN2.1 (R1.1)
unnamed: D11.2 (A), RN2.2 (R2.1)
unnamed: D12.2 (A), RN2.3 (R3.1)
unnamed: D13.2 (A), RN2.4 (R4.1)
unnamed: U1.1, U2.1
unnamed: U1.4, U2.2
unnamed: U1.10, U2.4
unnamed: U1.13, U2.5
unnamed: U2.3, U2.9
unnamed: U2.6, U2.10
unnamed: U2.11, U9.14 (D0)
unnamed: U3.7 (C0), U4.9 (C4)
P0: U4.5 (A1); also elsewhere on the board
P1: U4.3 (A2); also elsewhere on the board
P2: U4.14 (A3); also elsewhere on the board
P3: U4.12 (A4); also elsewhere on the board
P4: U3.5 (A1); also elsewhere on the board
P5: U3.3 (A2); also elsewhere on the board
P6: U3.14 (A3); also elsewhere on the board
P7: U3.12 (A4); also elsewhere on the board
Q0: U1.2, U6.4 (Za), U7.9 (A7)
Q1: U1.3, U6.7 (Zb), U7.8 (A6)
Q2: U1.5, U6.9 (Zc), U7.7 (A5)
Q3: U1.6, U6.12 (Zd), U7.6 (A4)
Q4: U1.8, U7.5 (A3), U8.4 (Za)
Q5: U1.9, U7.4 (A2), U8.7 (Zb)
Q6: U1.11, U7.3 (A1), U8.9 (Zc)
Q7: U1.12, U7.2 (A0), U8.12 (Zd)
S0: RN1.8 (R1.2), U4.4 (S1), U6.3 (I1a)
S1: RN1.7 (R2.2), U4.1 (S2), U6.6 (I1b)
S2: RN1.6 (R3.2), U4.13 (S3), U6.10 (I1c)
S3: RN1.5 (R4.2), U4.10 (S4), U6.13 (I1d)
S4: RN2.8 (R1.2), U3.4 (S1), U8.3 (I1a)
S5: RN2.7 (R2.2), U3.1 (S2), U8.6 (I1b)
S6: RN2.6 (R3.2), U3.13 (S3), U8.10 (I1c)
S7: RN2.5 (R4.2), U3.10 (S4), U8.13 (I1d)
SHR: J4.4, U5.12, U5.13
SU: R3.1, U4.7 (C0)
VCC: C1.1, C2.1, C3.1, C4.1, C5.1, C6.1, C7.1, C8.1, C9.1, J1.1, J2.1, J3.1, J4.1, J5.1, U1.14 (VCC), U2.14 (VCC), U3.16 (VCC), U4.16 (VCC), U5.14 (VCC), U6.16 (VCC), U7.1 (A->B), U7.20 (VCC), U8.16 (VCC), U9.16 (VCC); also elsewhere on the board
ZF: J4.8, R2.1, U9.4 (Q1)
ZFS: U2.8, U9.13 (D1)
~CLR: J4.5, U5.4, U5.5
~EO: U5.8, U7.19 (CE)
~FI: U5.3, U9.9 (E1), U9.10 (E2)
~SHR: U2.13, U5.11, U6.1 (S), U8.1 (S)

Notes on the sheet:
Control lines
Flag registers
Upper nibble
Check zero flag set
Source: http://6502.org/users/dieter/a1/a1_8.htm
Carry
Lower nibble


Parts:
U10, U11, U12, U13, U14, U15, U16, U17: 74HC153; SO-16_3.9x9.9mm_P1.27mm

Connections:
A0: U10.14 (S0); also elsewhere on the board
A1: U12.14 (S0); also elsewhere on the board
A2: U14.14 (S0); also elsewhere on the board
A3: U16.14 (S0); also elsewhere on the board
A4: U11.14 (S0); also elsewhere on the board
A5: U13.14 (S0); also elsewhere on the board
A6: U15.14 (S0); also elsewhere on the board
A7: U17.14 (S0); also elsewhere on the board
B0: U10.2 (S1); also elsewhere on the board
B1: U12.2 (S1); also elsewhere on the board
B2: U14.2 (S1); also elsewhere on the board
B3: U16.2 (S1); also elsewhere on the board
B4: U11.2 (S1); also elsewhere on the board
B5: U13.2 (S1); also elsewhere on the board
B6: U15.2 (S1); also elsewhere on the board
B7: U17.2 (S1); also elsewhere on the board
G0: U10.7 (Za); also elsewhere on the board
G1: U12.7 (Za); also elsewhere on the board
G2: U14.7 (Za); also elsewhere on the board
G3: U16.7 (Za); also elsewhere on the board
G4: U11.7 (Za); also elsewhere on the board
G5: U13.7 (Za); also elsewhere on the board
G6: U15.7 (Za); also elsewhere on the board
G7: U17.7 (Za); also elsewhere on the board
GND: U10.1 (Ea), U10.8 (GND), U10.15 (Eb), U11.1 (Ea), U11.8 (GND), U11.15 (Eb), U12.1 (Ea), U12.8 (GND), U12.15 (Eb), U13.1 (Ea), U13.8 (GND), U13.15 (Eb), U14.1 (Ea), U14.8 (GND), U14.15 (Eb), U15.1 (Ea), U15.8 (GND), U15.15 (Eb), U16.1 (Ea), U16.8 (GND), U16.15 (Eb), U17.1 (Ea), U17.8 (GND), U17.15 (Eb); also elsewhere on the board
IG0: U10.6 (I0a), U11.6 (I0a), U12.6 (I0a), U13.6 (I0a), U14.6 (I0a), U15.6 (I0a), U16.6 (I0a), U17.6 (I0a); also elsewhere on the board
IG1: U10.5 (I1a), U11.5 (I1a), U12.5 (I1a), U13.5 (I1a), U14.5 (I1a), U15.5 (I1a), U16.5 (I1a), U17.5 (I1a); also elsewhere on the board
IG2: U10.4 (I2a), U11.4 (I2a), U12.4 (I2a), U13.4 (I2a), U14.4 (I2a), U15.4 (I2a), U16.4 (I2a), U17.4 (I2a); also elsewhere on the board
IG3: U10.3 (I3a), U11.3 (I3a), U12.3 (I3a), U13.3 (I3a), U14.3 (I3a), U15.3 (I3a), U16.3 (I3a), U17.3 (I3a); also elsewhere on the board
IP0: U10.10 (I0b), U11.10 (I0b), U12.10 (I0b), U13.10 (I0b), U14.10 (I0b), U15.10 (I0b), U16.10 (I0b), U17.10 (I0b); also elsewhere on the board
IP1: U10.11 (I1b), U11.11 (I1b), U12.11 (I1b), U13.11 (I1b), U14.11 (I1b), U15.11 (I1b), U16.11 (I1b), U17.11 (I1b); also elsewhere on the board
IP2: U10.12 (I2b), U11.12 (I2b), U12.12 (I2b), U13.12 (I2b), U14.12 (I2b), U15.12 (I2b), U16.12 (I2b), U17.12 (I2b); also elsewhere on the board
IP3: U10.13 (I3b), U11.13 (I3b), U12.13 (I3b), U13.13 (I3b), U14.13 (I3b), U15.13 (I3b), U16.13 (I3b), U17.13 (I3b); also elsewhere on the board
P0: U10.9 (Zb); also elsewhere on the board
P1: U12.9 (Zb); also elsewhere on the board
P2: U14.9 (Zb); also elsewhere on the board
P3: U16.9 (Zb); also elsewhere on the board
P4: U11.9 (Zb); also elsewhere on the board
P5: U13.9 (Zb); also elsewhere on the board
P6: U15.9 (Zb); also elsewhere on the board
P7: U17.9 (Zb); also elsewhere on the board
VCC: U10.16 (VCC), U11.16 (VCC), U12.16 (VCC), U13.16 (VCC), U14.16 (VCC), U15.16 (VCC), U16.16 (VCC), U17.16 (VCC); also elsewhere on the board

Board: 2 copper layers, 51 parts (5 on the bottom side), 101 nets, no tracks yet.

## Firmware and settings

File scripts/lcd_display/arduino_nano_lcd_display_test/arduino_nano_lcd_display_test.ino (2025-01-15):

#define ENABLE (1 << 0)
#define RS     (1 << 1)
#define DELAY_SMALL 10
#define DELAY_LARGE 100

// Function prototypes

void lcdcommand(uint8_t cmd, uint8_t r = 0);
void lcddata(uint8_t data);
void lcdinit();
void lcdprint(const char *str);

void setup() {
  DDRF = 0xFF;        // use port F as output
  PORTF = 0x00;

  lcdinit();
  lcdprint("Hello, World!");
  lcdcommand(0xC0);
  lcdprint("Hello, SAP");
}

void loop() {
}

void lcdcommand(uint8_t cmd, uint8_t r) {
  // upper byte
  uint8_t ins = (cmd & 0xF0) | r;
  PORTF = ins;
  delayMicroseconds(DELAY_SMALL);
  PORTF = ins | ENABLE;
  delayMicroseconds(DELAY_SMALL);
  PORTF = ins;
  delayMicroseconds(DELAY_LARGE);

  // lower byte
  ins = ((cmd & 0x0F) << 4) | r;
  PORTF = ins;
  delayMicroseconds(DELAY_SMALL);
  PORTF = ins | ENABLE;
  delayMicroseconds(DELAY_SMALL);
  PORTF = ins;
  delayMicroseconds(DELAY_LARGE);
}

void lcddata(uint8_t cmd) {
  lcdcommand(cmd, RS);
}

void lcdprint(const char *str) {
  while(*str != '\0') {
    lcddata(*str++);
  }
}

void lcdinit() {
  lcdcommand(0x33); // set 8-bit mode
  lcdcommand(0x32); // set 4-bit mode
  lcdcommand(0x28); // 4-bit mode, 2 lines, 5x8 font
  lcdcommand(0x01); // clear display
  lcdcommand(0x06); // entry mode: moves cursor to right
  delay(5);
  lcdcommand(0x0C); // display on, cursor off
  delay(DELAY_LARGE);       // Wait for clear command to complete
}

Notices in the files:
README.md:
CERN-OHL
